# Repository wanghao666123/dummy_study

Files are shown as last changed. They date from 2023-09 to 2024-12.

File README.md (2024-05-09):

# Dummy
稚晖君dummy复制，目标是全国产谐波减速器，价格在3000元之内！
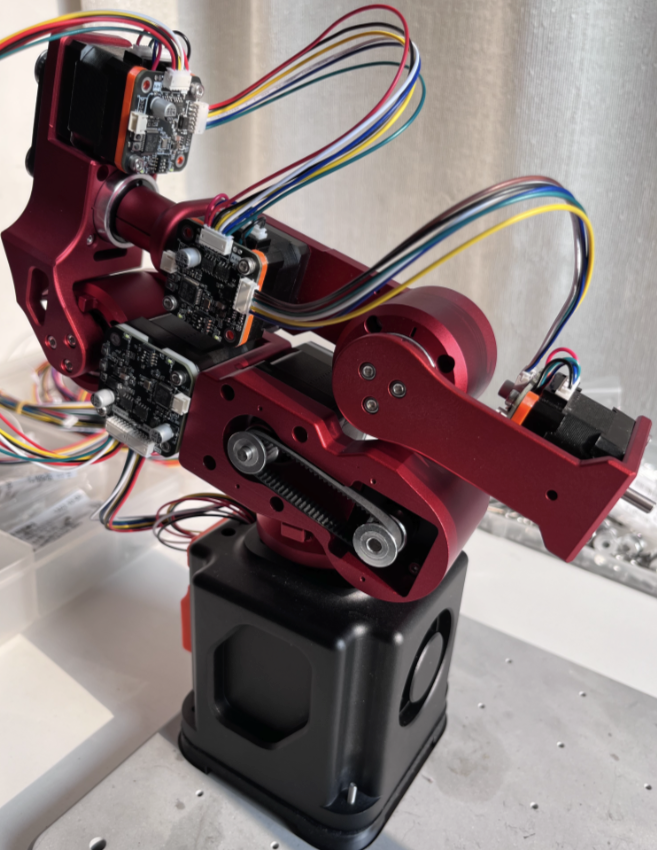
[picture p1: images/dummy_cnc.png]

1. 目录描述
- Firmware 包括ref控制板，42，35驱动板所用源代码
- Hardware 重新设计包括ref控制板，42，35驱动板schematic, pcb所有文件
- 3d-model 所有复制dummy 3d打印文件
- ESP32-iot esp32 supports files

1. 重新设计的ref控制板
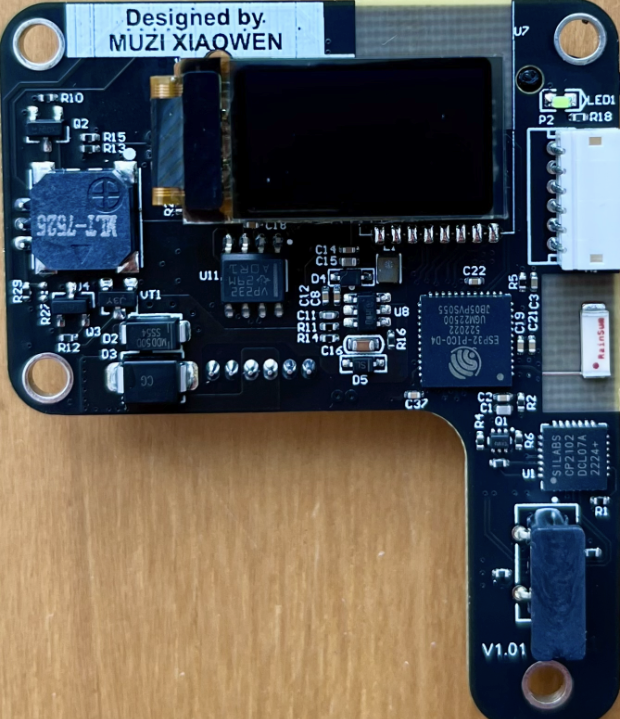
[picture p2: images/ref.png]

- 简化设计，更适合量产
1. 修改所有1.0mm的连接器为插针1.5mm，fix原版连接器容易脱落
1. 删除base板，将base板子集成到了主板上
1. 添加switching ldo，供电电流最大2A，fix原版mcu ldo电流过小，温度过高issue
1. 将led ring，buzzer 控制从ESP32 改到stm32 mcu
1. 更合理的布局
1. 降低量产成本

1. 重新设计的42/35驱动板

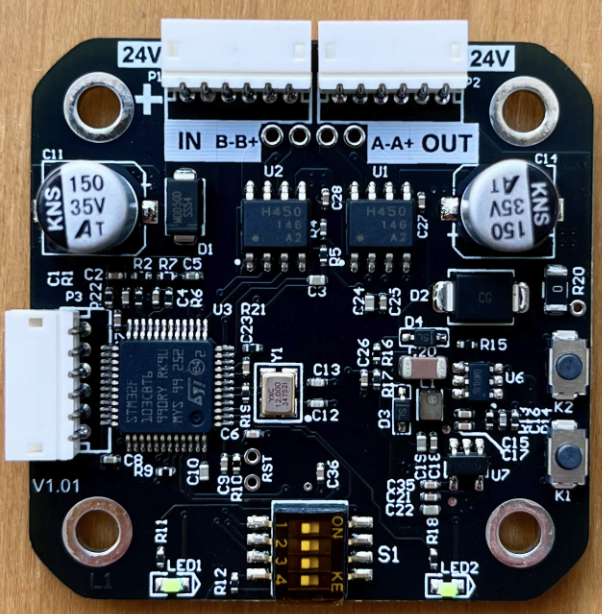
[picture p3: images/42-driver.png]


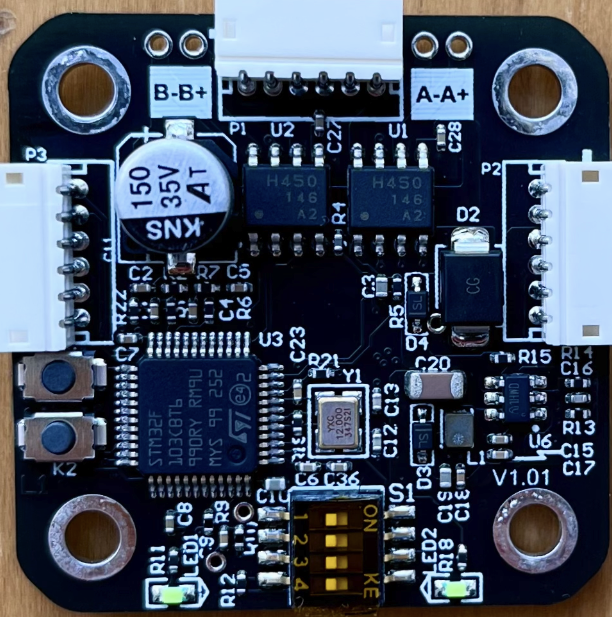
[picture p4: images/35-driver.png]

- 42/35驱动板正式版
1. 所有连接器改为1.5mm 3A 座子，更适合量产
1. 电源线复用两根1007/26号线，最大支持到3A
1. CAN BUS ID 通过板载拨码开关设置

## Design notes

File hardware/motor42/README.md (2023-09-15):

对比原始设计，优化了 PCB布局，模拟信号隔离，模拟电源隔离，隔离CAN总线，添加120欧姆终端电阻开关，加大了电源电容优化高转速启动性能，同时添加了多个低容值陶瓷电容优化了高频抗干扰性，提高了校验可靠性，提高了drive芯片的散热性能

--原理图基于并且拥有者稚晖君，原理图修改版和PCB设计木子晓文。--

Based on ZhiHuiJun schematic, the oringal design owned by ZhiHuiJun. Schematic modified and PCB designed by Muzi Xiaowen. 
The schematic and PCB design are free and open, and comes with ABSOLUTELY NO WARRANTY, to the extent permitted by applicable law.

References
https://github.com/peng-zhihui/Dummy-Robot

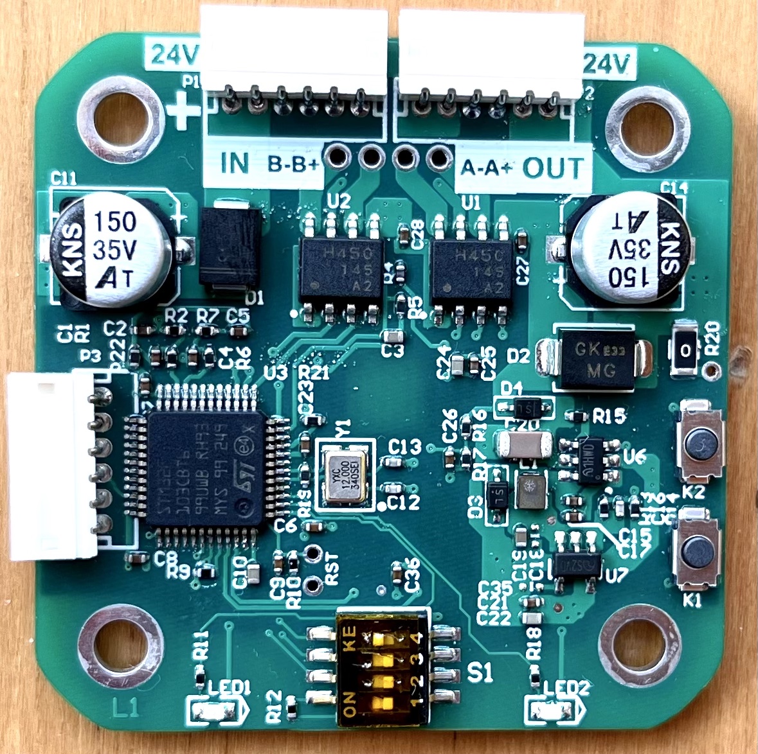
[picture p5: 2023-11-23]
images/m42.jpg

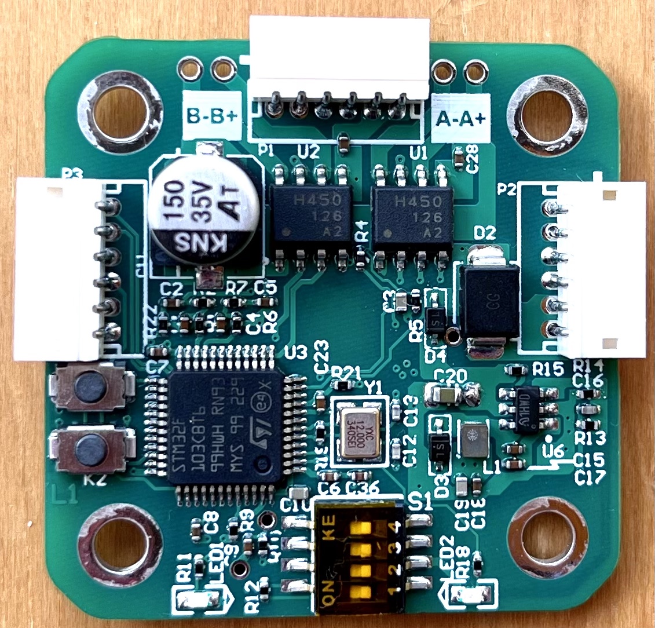
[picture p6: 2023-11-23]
images/m35.jpg

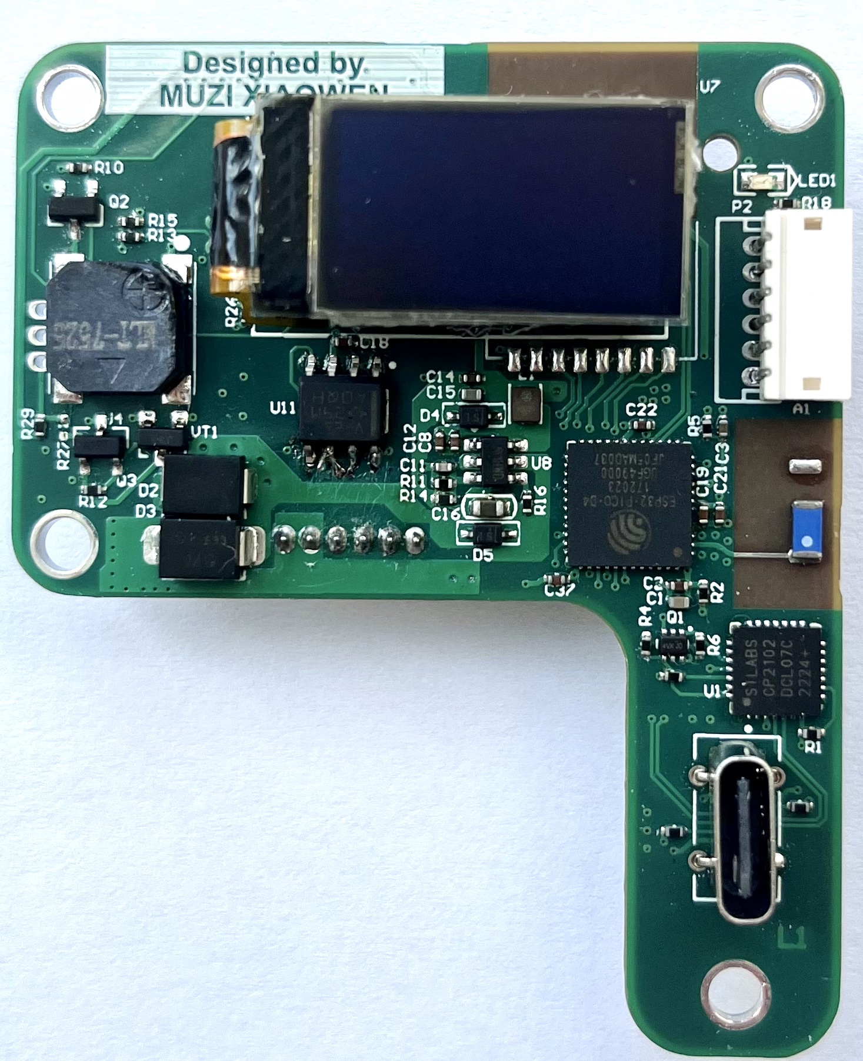
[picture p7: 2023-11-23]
images/controller_top.jpg

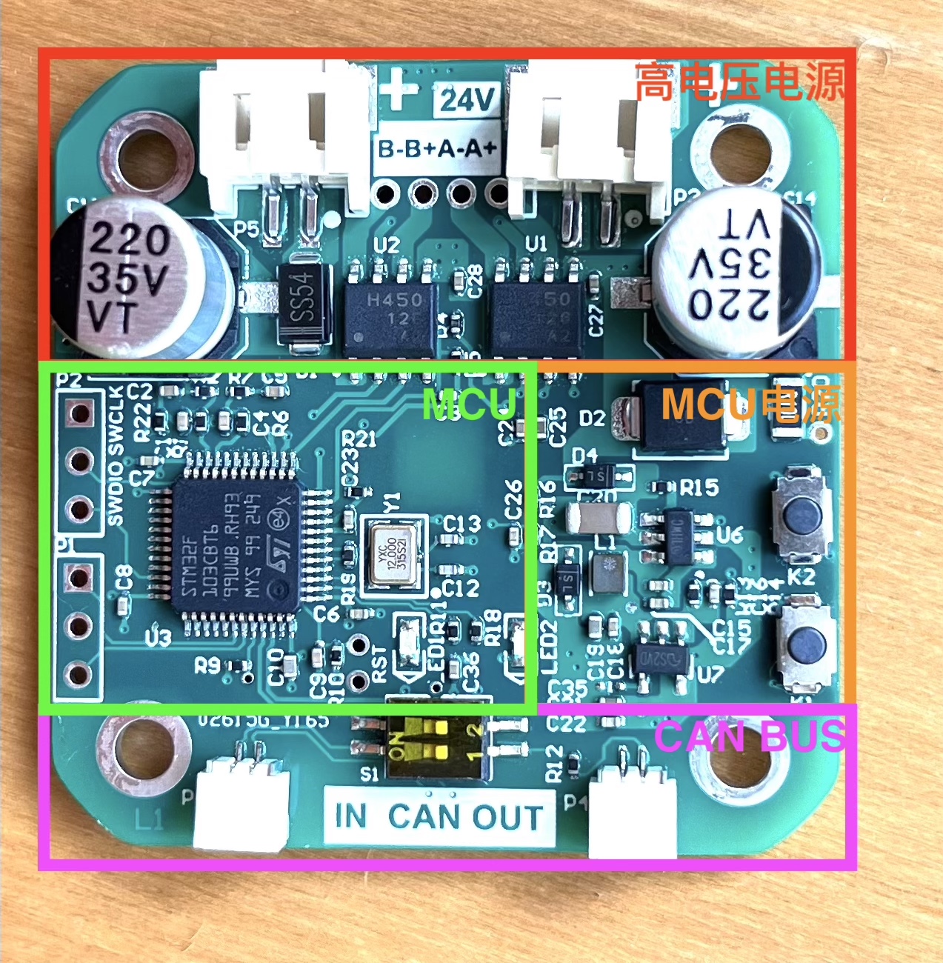
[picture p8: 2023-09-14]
images/top.jpg

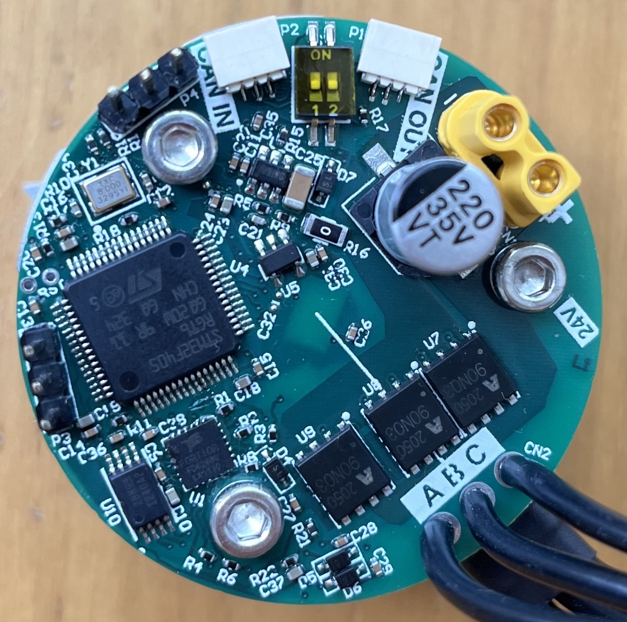
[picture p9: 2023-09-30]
images/bldc.jpg

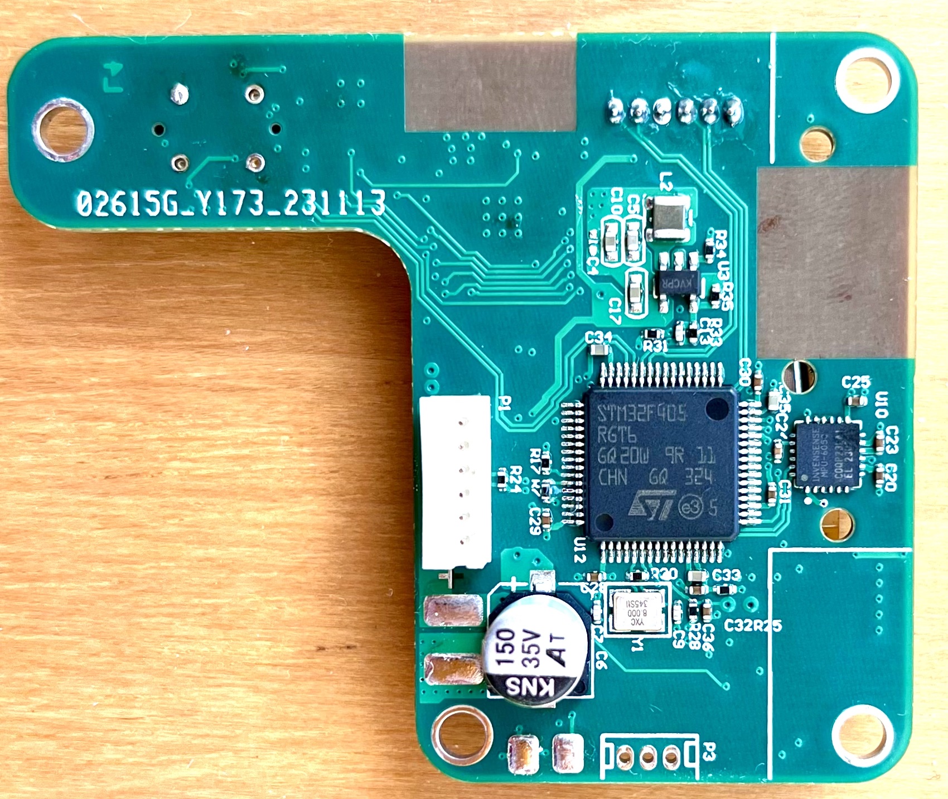
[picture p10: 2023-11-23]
images/controller_bot.jpg

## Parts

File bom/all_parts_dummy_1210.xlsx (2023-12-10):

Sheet: Motor-42
Comment | Description | Designator | Footprint | LibRef | Quantity
0.1uF | Capacitor | C1, C2, C4, C5, C6, C7, C8, C9, C15, C17, C18, C21, C25, C26 | CAP_0402 | 电容-0402 | 14
10uF | Capacitor | C3, C10, C19, C22, C24 | CAP_0402 | 电容-0402 | 5
100uF | Capacitor | C11, C12, C13, C14 | 1206-CAP | 电容-1206 | 4
100pF | Capacitor | C16 | CAP_0402 | 电容-0402 | 1
10uF/50V | Capacitor | C20 | CAP_0402 | 电容-0402 | 1
10nF | Capacitor | C23 | CAP_0402 | 电容-0402 | 1
SS54 | Diode | D1 | DO-214AC | Diode_SMA | 1
SMBJ28CA |  | D2 | SMBJ-CA_MFG | SMBJ28CA | 1
二极管-5819W | 40V | D3, D4 | SOD-323 | 二极管-5819W | 2
跳线 | Resistor | J1 | 0402-0R | 跳线 | 1
TACT 2P | Button | K1, K2 | ButtonTACT_3x4x2_180 | ButtonTACT_3x4x2_180 | 2
6.8uH |  | L1 | IND-201612 | 电感-201612 | 1
SH1.0-5P |  | P1 | SH1.0-5P | SH1.0-5P | 1
SH1.0-6P |  | P2, P3, P4 | SH1.0-6P | SH1.0-6P | 3
SH1.0-3P | Header | P5 | SH1.0-3P | SH1.0-3P | 1
1K | Resistor | R1, R2, R6, R7, R17 | RES_0402 | 电阻-0402 | 5
0.1R | Resistor | R3, R8 | 1206-RES | 电阻-1206 | 2
NCP15XH103F03RC | THERMISTOR 10K OHM NTC 0402 SMD | R4 | RES_0402 | NCP15XH103F03RC | 1
3.3K | Resistor | R5 | RES_0402 | 电阻-0402 | 1
10K | Resistor | R9, R10, R13, R16 | RES_0402 | 电阻-0402 | 4
120R | Resistor | R11, R12 | RES_0402 | 电阻-0402 | 2
1.8K | Resistor | R14 | RES_0402 | 电阻-0402 | 1
1M | Resistor | R15 | RES_0402 | 电阻-0402 | 1
测试点 |  | T1, T2 | TEST_PT | 测试点 | 2
TB67H450FNG | PWM Chopper Type DC Brushed Motor Driver | U1, U2 | SO-8-PAD | TB67H450FNG | 2
STM32F103CBT6 | ARM Cortex-M3 32-bit MCU, 128 KB Flash, 20 KB Internal RAM, 37 I/Os, 48-pin LQFP, -40 to 85 degC, Tray | U3 | LQFP-48 | STM32F103CBT6 | 1
TL431IDBZT | Adjustable precision shunt regulator 3-SOT-23 -40 to 85 | U4 | SOT23-3 | TL431IDBZT | 1 | taobao
SN65HVD232D |  | U5 | SO-8 | SN65HVD232D | 1
ME3116 | DC-DC | U6 | SOT23-6 | ME3116 | 1
LP2992 3V3 | LDO | U7 | SOT23-5 | LP2992 | 1
MT6816 | Magnetic Position Sensor | U8 | SO-8 | MT6816 | 1
12MHz | 村田贴片 | Y1 | 晶振-3P | 晶振-3Pin | 1 | taobao

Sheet: Motor-20
Comment | Description | Designator | Footprint | LibRef | Quantity
0.1uF | Capacitor | C1, C2, C3, C4, C5, C6, C7, C8, C11, C15, C16, C20, C21 | CAP_0402 | 电容-0402 | 13
100uF | Capacitor | C9, C10 | 1206-CAP | 电容-1206 | 2
10uF | Capacitor | C12, C17, C18, C19 | CAP_0402 | 电容-0402 | 4
10nF | Capacitor | C13 | CAP_0402 | 电容-0402 | 1
100pF | Capacitor | C14 | CAP_0402 | 电容-0402 | 1
SS54 | Diode | D1 | DO-214AC | Diode_SMA | 1
SMBJ28CA |  | D2 | SMBJ-CA_MFG | SMBJ28CA | 1
二极管-5819W | 40V | D3, D4 | SOD-323 | 二极管-5819W | 2
跳线 | Resistor | J1 | 0402-0R | 跳线 | 1
TACT 2P | Button | K1, K2 | ButtonTACT_3x4x2_180 | ButtonTACT_3x4x2_180 | 2
6.8uH |  | L1 | IND-201612 | 电感-201612 | 1
SH1.0-2P |  | P1, P2 | SH1.0-2P | SH1.0-2P | 2
SH1.0-3P | Header | P3 | SH1.0-3P | SH1.0-3P | 1
1K | Resistor | R1, R2, R4, R5, R14 | RES_0402 | 电阻-0402 | 5
0.1R | Resistor | R3, R6 | 1206-RES | 电阻-1206 | 2
10K | Resistor | R7, R8, R10, R13 | RES_0402 | 电阻-0402 | 4
120R | Resistor | R9 | RES_0402 | 电阻-0402 | 1
1.8K | Resistor | R11 | RES_0402 | 电阻-0402 | 1
1M | Resistor | R12 | RES_0402 | 电阻-0402 | 1
TB67H450FNG | PWM Chopper Type DC Brushed Motor Driver | U1, U2 | SO-8-PAD | TB67H450FNG | 2
STM32F103CBT6 | ARM Cortex-M3 32-bit MCU, 128 KB Flash, 20 KB Internal RAM, 37 I/Os, 48-pin LQFP, -40 to 85 degC, Tray | U3 | LQFP-48 | STM32F103CBT6 | 1
SN65HVD232D |  | U4 | SO-8 | SN65HVD232D | 1
LP2992 3V3 | LDO | U5 | SOT23-5 | LP2992 | 1
ME3116 | DC-DC | U6 | SOT23-6 | ME3116 | 1
MT6816 | Magnetic Position Sensor | U7 | SO-8 | MT6816 | 1
12MHz | 村田贴片 | Y1 | 晶振-3P | 晶振-3Pin | 1 | taobao

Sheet: REF-UNIT
Comment | Description | Designator | Footprint | LibRef | Quantity
OLED-12880 |  | 1 | OLED-12880 | OLED-12880 | 1
0.1uF | Capacitor | C1, C6, C7, C9, C12, C13, C14, C15, C16, C20 | CAP_0402 | 电容-0402 | 10
10uF | Capacitor | C2, C5, C10, C11, C17, C18, C19 | CAP_0402 | 电容-0402 | 7
10nF | Capacitor | C3, C4 | CAP_0402 | 电容-0402 | 2
2.2nF | Capacitor | C8 | CAP_0402 | 电容-0402 | 1
color? | LED | D1 | LED_0402_RED | LED_0402 | 1
B2B-Connector-28P-0.5mm |  | J1, J2 | B2B-0.5mm-28P-M | B2B-Connector-28P-0.5mm | 2
2K | Resistor | R1, R2, R3 | RES_0402 | 电阻-0402 | 3
4.7K | Resistor | R4, R5, R8 | RES_0402 | 电阻-0402 | 3
10K | Resistor | R6, R13 | RES_0402 | 电阻-0402 | 2
560K | Resistor | R7 | RES_0402 | 电阻-0402 | 1
120R/NC | Resistor | R9 | RES_0402 | 电阻-0402 | 1
0R | Resistor | R10, R11 | RES_0402 | 电阻-0402 | 2
22R | Resistor | R12, R14 | RES_0402 | 电阻-0402 | 2
LP2992 3V3 | LDO | U1 | SOT23-5 | LP2992 | 1
MPU6050 | 六轴传感器 | U2 | QFN-24 | MPU6050 | 1
SN65HVD232D |  | U3 | SO-8 | SN65HVD232D | 1
STM32F405RGT6 | ARM Cortex-M4 32-bit MCU+FPU, 210 DMIPS, 1024 kB Flash, 192 kB Internal RAM, 51 I/Os, 64-pin LQFP, -40 to 85 degC, Tray | U4 | LQFP-64_N | STM32F405RGT6 | 1
8MHz | 村田贴片 | Y1 | 晶振-3P | 晶振-3Pin | 1 | taobao

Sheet: REF-Base
Comment | Description | Designator | Footprint | LibRef | Quantity
RAINSUN |  | A1 | ANT-Rainsun-AN5120 | ANT-Rainsun-AP5120 | 1
10uF | Capacitor | C1, C5, C10, C15 | CAP_0402 | 电容-0402 | 4
0.1uF | Capacitor | C2, C4, C8, C9, C12, C14 | CAP_0402 | 电容-0402 | 6
1uF | Capacitor | C3 | CAP_0402 | 电容-0402 | 1
100uF | Capacitor | C6 | 1206-CAP | 电容-1206 | 1 | 22uF/35V
10nF | Capacitor | C7, C13 | CAP_0402 | 电容-0402 | 2
100pF | Capacitor | C11 | CAP_0402 | 电容-0402 | 1
10uF/50V | Capacitor | C16 | CAP_0402 | 电容-0402 | 1 | 2.2uF/35V
color? | LED | D1 | LED_0402_RED | LED_0402 | 1
SS54 | Diode | D2 | DO-214AC | Diode_SMA | 1
SMBJ28CA |  | D3 | SMBJ-CA_MFG | SMBJ28CA | 1
二极管-5819W | 40V | D4, D5 | SOD-323 | 二极管-5819W | 2
USB-TYPE-C-STAND |  | J1 | USB-TYPE-C-STAND | USB-TYPE-C-STAND | 1
6.8uH |  | L1 | IND-201612 | 电感-201612 | 1
SH1.0-5P |  | P1 | SH1.0-5P | SH1.0-5P | 1
SH1.0-2P |  | P2, P3, P4 | SH1.0-2P | SH1.0-2P | 3
SH1.0-3P | Header | P5, P6 | SH1.0-3P | SH1.0-3P | 2
BC847BVC-7 |  | Q1 | SOT563-6 | BC847BVC-7 | 1
AO3400A | N-MOS | Q2 | SOT23-3 | AO3400A | 1
AO3401A | P-MOS | Q3 | SOT23-3 | AO3401A | 1
10K | Resistor | R1, R5, R10, R11, R15 | RES_0402 | 电阻-0402 | 5
0R | Resistor | R2 | RES_0402 | 电阻-0402 | 1
200R | Resistor | R3 | RES_0402 | 电阻-0402 | 1
12K | Resistor | R4, R6 | RES_0402 | 电阻-0402 | 2
2K | Resistor | R7, R12 | RES_0402 | 电阻-0402 | 2
5.1K | Resistor | R8, R9 | RES_0402 | 电阻-0402 | 2
1K | Resistor | R13 | RES_0402 | 电阻-0402 | 1
1.8K | Resistor | R14 | RES_0402 | 电阻-0402 | 1
1M | Resistor | R16 | RES_0402 | 电阻-0402 | 1
REF-Unit | Robot Embedded Framework based on STM43F405RGT6. | S1 | REF-UNIT | REF-Unit | 1
CP2102 | USB转TTL | U1 | QFN-28 | CP2102 | 1
ESP32_SIP |  | U2 | QFN-48_7X7 | ESP32-PICO | 1
LP2992 3V3 | LDO | U3, U6 | SOT23-5 | LP2992 | 2
DET402 |  | U4 | DET402 | DET402 | 1
SN65HVD232D |  | U5 | SO-8 | SN65HVD232D | 1
NRF24L01 |  | U7 | NRF24L01-MODULE | NRF24L01模块 | 1
ME3116 | DC-DC | U8 | SOT23-6 | ME3116 | 1
S8050 | Surface mount NPN transistor, package SOT-23 | VT1 | SMT_TRIODE_NPN | SMT_TRIODE_NPN | 1

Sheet: screws
 |  | 数量
J1
M4*21mm |  | 2
M4*12MM | mini11 减速器到base外壳 | 2
M3*34MM | 42电机 | 4
M3*5MM | mini11 减速器适配件固定到42电机 | 2
M3*20MM | j1 固定到外壳 | 6
M3*18MM | j1 连杆固定到j2减速器 | 3
固定底座
M3*28MM | 固定到底座 | 4
J2/J3
M3*25 | 固定j2/j3减速器适配件 | 4
M3*30 | 固定j2/j3减速器到连杆 | 4
M3*15 | 固定j2 42 Motor到连杆 | 4
M3*42 | 固定3个 42 Motor 驱动板 | 12
M3*11MM | 固定j3 42 Motor到连杆 | 4
Joint4
M3*6MM | 固定j4 35 Motor到连杆 | 4
M3*13MM | 固定3个 35 Motor 驱动板 | 12
M3*13Mm | 固定j4减速器到连杆 | 3
Joint5
M3*8MM | 固定2个 35 Motor 到连杆 | 4
M3*19MM | 固定j5减速器到连杆 | 1

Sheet: 3d
 |  | 数量
Base.stl | joint1底座 | 1
joint23.stl | joint23联杆 | 1
joint4.stl | joint4联杆 | 1
joint5.stl | joint5联杆 | 1
joint6.stl | joint6联杆 | 1
mini11-bracket-metal.stl | mini11与42电机连接支架 | 1
mini8-bracket-metal.stl | mini8谐波连接支架 | 4
motor42-bracket-top-metal.stl | 42驱动板散热顶盖 | 3
motor35-bracket-top-metal.stl | 35驱动板散热顶盖 | 2

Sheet: parts
42电机驱动板 |  | 3 | b站 木子晓汶 工房
35电机驱动板 |  | 3 | b站 木子晓汶 工房
42 电机 | l=40 1a | 3 | https://item.taobao.com/item.htm?id=549501040122&ns=1&abbucket=13
35 电机 | l=28 1a | 3 | https://item.taobao.com/item.htm?spm=a1z09.2.0.0.17872e8dTWSTmP&id=15168111895&_u=83jnrl7aaaff
减速器 | mini11 | 1 | taobao
减速器 | mini8 | 5 | taobao
同步轮 | 20齿内孔5mm外径18 | 8 | https://item.taobao.com/item.htm?spm=a1z09.2.0.0.19b12e8dfRIPU3&id=625483500699&_u=a3jnrl7adc93
同步皮带 | 152mm | 1 | https://item.taobao.com/item.htm?spm=a1z09.2.0.0.19b12e8dfRIPU3&id=626759355655&_u=a3jnrl7aa476
同步皮带 | 120mm | 1 | https://item.taobao.com/item.htm?spm=a1z09.2.0.0.19b12e8dfRIPU3&id=626759355655&_u=a3jnrl7aa476
同步皮带 | 110mm | 1 | https://item.taobao.com/item.htm?spm=a1z09.2.0.0.19b12e8dfRIPU3&id=626759355655&_u=a3jnrl7aa476
同步皮带 | 184mm | 1 | https://item.taobao.com/item.htm?spm=a1z09.2.0.0.19b12e8dfRIPU3&id=626759355655&_u=a3jnrl7aa476
电源开关 | 开孔直径：16mm，12-24v | 1 | https://item.taobao.com/item.htm?spm=a1z09.2.0.0.6dcd2e8dgKFAl1&id=589544046782&_u=93jnrl7aceb2
DC电源插座 | DC5.5*2.5mm | 1 | https://item.taobao.com/item.htm?spm=a1z09.2.0.0.6dcd2e8dgKFAl1&id=679108658727&_u=93jnrl7a3b6f
电源 | 24v 6a | 1 | https://item.taobao.com/item.htm?spm=a1z09.2.0.0.6dcd2e8dgKFAl1&id=552809889509&_u=93jnrl7a25cd
6pin排线 | zh1.5mm 30CM(定做) | 1 | https://detail.tmall.com/item.htm?_u=93jnrl7a54c7&id=642559605753&spm=a1z09.2.0.0.6dcd2e8dgKFAl1
6pin排线 | zh1.5mm 20CM(定做) | 6 | https://detail.tmall.com/item.htm?_u=93jnrl7a54c7&id=642559605753&spm=a1z09.2.0.0.6dcd2e8dgKFAl1

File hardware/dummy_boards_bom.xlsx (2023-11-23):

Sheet: REF
Comment | Quantity | Designator | Footprint | Layer
0R | 4 | R2, R26, R27, R29 | RES_0402_1 | Top
0.1uF | 9 | C2, C8, C12, C14, C18, C19, C21, C22, C37 | CAP_0402 | Top
1K | 1 | R13 | RES_0402_1 | Top
1M | 1 | R16 | RES_0402_1 | Top
1uF | 1 | C3 | CAP_0402 | Top
1.8K | 1 | R14 | RES_0402_1 | Top
2K | 2 | R12, R18 | RES_0402_1 | Top
4.7K | 3 | R19, R20, R23 | RES_0402_1 | Top
4.7uF | 1 | C16 | C0603 | Top
5.1K | 2 | R8, R9 | RES_0402_1 | Top
6.8uH | 1 | L1 | IND-201612 | Top
10K | 6 | R1, R5, R10, R11, R15, R21 | RES_0402_1 | Top
10uF | 4 | C1, C15, C26, C27 | CAP_0402 | Top
12K | 2 | R4, R6 | RES_0402_1 | Top
100pF | 1 | C11 | CAP_0402 | Top
200R | 1 | R3 | RES_0402_1 | Top
560K | 1 | R22 | RES_0402_1 | Top
AO3400A | 1 | Q2 | SOT23-3 | Top
AO3401A | 1 | Q3 | SOT23-3 | Top
BC847BVC-7 | 1 | Q1 | SOT563-6 | Top
CP2102 | 1 | U1 | QFN-28 | Top
ESP32_SIP | 1 | U2 | QFN-48_7X7 | Top
Header 6H | 1 | P2 | CONN-TH_HC-ZH1.5-6A-s | Top
LED GREEN | 1 | LED1 | LED-0603 | Top
ME3116 | 1 | U8 | SOT23-6 | Top
MLT-7525 | 1 | U4 | BUZ-SMD_4P-L7.5-W7.5-P7.59-TL | Top
NRF24L01 | 1 | U7 | NRF24L01-MODULE | Top
OLED-12880 | 1 | 1 | OLED-12880 | Top
RAINSUN | 1 | A1 | ANT-Rainsun-AN5120 | Top
S8050 | 1 | VT1 | SMT_TRIODE_NPN | Top
SMBJ28CA | 1 | D3 | SMBJ-CA_MFG | Top
SN65HVD232D | 1 | U11 | SO-8 | Top
SS54 | 1 | D2 | DO-214AC | Top
USB-TYPE-C-STAND | 1 | J1 | USB-TYPE-C-STAND | Top
b5819W | 2 | D4, D5 | SOD-323 | Top
0R | 2 | R25, R31 | RES_0402_1 | Bottom
0.1uF | 10 | C4, C20, C23, C25, C28, C29, C30, C31, C32, C36 | CAP_0402 | Bottom
1M | 1 | R30 | RES_0402 | Bottom
2K | 2 | R7, R17 | RES_0402_1 | Bottom
2.2nF | 1 | C24 | CAP_0402 | Bottom
2.2uH | 1 | L2 | IND-252012A-2R2 | Bottom
10K | 2 | R28, R34 | RES_0402_1 | Bottom
10uF | 3 | C33, C34, C35 | CAP_0402 | Bottom
20pF | 2 | C7, C9 | CAP_0402 | Bottom
20pF | 1 | C13 | CAP_0402 | Bottom
22uF | 3 | C5, C10, C17 | C0603 | Bottom
22.1K | 1 | R35 | RES_0402_1 | Bottom
100K | 1 | R33 | RES_0402_1 | Bottom
120R/NC | 1 | R24 | RES_0402_1 | Bottom
220uF/25V | 1 | C6 | CAP-SMD_BD8.0-L8.3-W8.3-LS9.3-FD | Bottom
Header 3 | 1 | P3 | CONN-TH_HC-ZH1.5-3A-S | Bottom
Header 6H | 1 | P1 | CONN-TH_HC-ZH1.5-6A | Bottom
MPU6050 | 1 | U10 | QFN-24 | Bottom
STM32F405RGT6 | 1 | U12 | LQFP-64_N | Bottom
SY8089 2A | 1 | U3 | SOT23-5 | Bottom
XTAL-4 | 1 | Y1 | LC-SMD-3225_4P | Bottom

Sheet: Motor-42
Comment | Description | Designator | Footprint | Quantity | Layer
0.1R | Resistor | R3, R8 | 1206-RES | 2 | Bottom
10uF/50V | Capacitor, chip, ceramic | C29, C30, C31, C32, C33, C34 | 1206-CAP | 6 | Bottom
MT6816 | Magnetic Position Sensor | U8 | SO-8 | 1 | Bottom
SN65HVD232D |  | U5 | so-8 | 1 | Bottom
0 | Resistor | R21, R22 | RES_0402 | 2 | Top
0R | Resistor | R20 | 1206-RES | 1 | Top
0.1uF | Capacitor | C1, C2, C4, C5, C6, C7, C8, C9, C15, C17, C18, C21, C23, C25, C26, C27, C28, C35, C36 | CAP_0402 | 19 | Top
1K | Resistor | R1, R2, R6, R7, R11, R17, R18 | RES_0402 | 7 | Top
1M | Resistor | R15, R19 | RES_0402 | 2 | Top
1.8K | Resistor | R14 | RES_0402 | 1 | Top
3.3K | Resistor | R5 | RES_0402 | 1 | Top
6.8uH |  | L1 | IND-201612 | 1 | Top
10K | Resistor | R9, R10, R13, R16 | RES_0402 | 4 | Top
10uF | Capacitor | C3, C10, C19, C22, C24 | CAP_0402 | 5 | Top
10uF/50V | Capacitor | C20 | 1206-CAP | 1 | Top
20pF | Capacitor | C12, C13 | CAP_0402 | 2 | Top
100pF | Capacitor | C16 | CAP_0402 | 1 | Top
120R | Resistor | R12 | RES_0402 | 1 | Top
220uF/25V | Capacitor, chip, ceramic | C11, C14 | CAP-SMD_BD8.0-L8.3-W8.3-LS9.3-FD | 2 | Top
DSHP04TSGER | DIP Switches / SIP Switches 4 pos. low profile Btm Seal Tape J Bend | S1 | SW-SMD_DSHP04TS-S | 1 | Top
Header 6H | Header, 6-Pin, Right Angle | P1, P2, P3 | CONN-TH_HC-ZH1.5-6A-s | 3 | Top
LED GREEN | LED GRN SGL RA 25mA 4.1V SMD | LED1, LED2 | LED-0603 | 2 | Top
LP2992 3V3 | LDO | U7 | SOT23-5 | 1 | Top
ME3116 | DC-DC | U6 | SOT23-6 | 1 | Top
NCP15XH103F03RC | THERMISTOR 10K OHM NTC 0402 SMD | R4 | RES_0402 | 1 | Top
SMBJ28CA |  | D2 | SMBJ-CA_MFG | 1 | Top
SS54 | Diode | D1 | DO-214AC | 1 | Top
STM32F103CBT6 | ARM Cortex-M3 32-bit MCU, 128 KB Flash, 20 KB Internal RAM, 37 I/Os, 48-pin LQFP, -40 to 85 degC, Tray | U3 | LQFP-48 | 1 | Top
TACT 2P | Button | K1, K2 | ButtonTACT_3x4x2_180 | 2 | Top
TB67H450FNG | PWM Chopper Type DC Brushed Motor Driver | U1, U2 | SO-8-PAD | 2 | Top
XTAL-4 | Crystal | Y1 | LC-SMD-3225_4P | 1 | Top
二极管-5819W | 40V | D3, D4 | SOD-323 | 2 | Top

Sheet: Motor-35
Comment | Quantity | Description | Designator | Footprint | Layer
0R | 1 | Resistor | R20 | 1206-RES | Bottom
0.1R | 2 | Resistor | R3, R8 | 1206-RES | Bottom
0.1uF | 2 | Capacitor | C21, C25 | CAP_0402 | Bottom
10uF | 2 | Capacitor | C22, C24 | CAP_0402 | Bottom
10uF/50V | 4 | Capacitor, chip, ceramic | C29, C30, C31, C32 | 1206-CAP | Bottom
LP2992 3V3 | 1 | LDO | U7 | SOT23-5 | Bottom
MT6816 | 1 | Magnetic Position Sensor | U8 | SO-8 | Bottom
SN65HVD232D | 1 |  | U5 | so-8 | Bottom
SS54 | 1 | Diode | D1 | DO-214AC | Bottom
0 | 2 | Resistor | R21, R22 | RES_0402 | Top
0.1uF | 15 | Capacitor | C1, C2, C4, C5, C6, C7, C8, C9, C15, C17, C18, C23, C27, C28, C36 | CAP_0402 | Top
1K | 6 | Resistor | R1, R2, R6, R7, R11, R18 | RES_0402 | Top
1M | 2 | Resistor | R15, R19 | RES_0402 | Top
1.8K | 1 | Resistor | R14 | RES_0402 | Top
3.3K | 1 | Resistor | R5 | RES_0402 | Top
6.8uH | 1 |  | L1 | IND-201612 | Top
10K | 3 | Resistor | R9, R10, R13 | RES_0402 | Top
10uF | 3 | Capacitor | C3, C10, C19 | CAP_0402 | Top
10uF/50V | 1 | Capacitor | C20 | 1206-CAP | Top
20pF | 2 | Capacitor | C12, C13 | CAP_0402 | Top
100pF | 1 | Capacitor | C16 | CAP_0402 | Top
120R | 1 | Resistor | R12 | RES_0402 | Top
220uF/25V | 1 | Capacitor, chip, ceramic | C11 | CAP-SMD_BD8.0-L8.3-W8.3-LS9.3-FD | Top
DSHP04TSGER | 1 | DIP Switches / SIP Switches 4 pos. low profile Btm Seal Tape J Bend | S1 | SW-SMD_DSHP04TS-S | Top
Header 6H | 3 | Header, 6-Pin, Right Angle | P1, P2, P3 | CONN-TH_HC-ZH1.5-6A-s | Top
LED GREEN | 2 | LED GRN SGL RA 25mA 4.1V SMD | LED1, LED2 | LED-0603 | Top
ME3116 | 1 | DC-DC | U6 | SOT23-6 | Top
NCP15XH103F03RC | 1 | THERMISTOR 10K OHM NTC 0402 SMD | R4 | RES_0402 | Top
SMBJ28CA | 1 |  | D2 | SMBJ-CA_MFG | Top
STM32F103CBT6 | 1 | ARM Cortex-M3 32-bit MCU, 128 KB Flash, 20 KB Internal RAM, 37 I/Os, 48-pin LQFP, -40 to 85 degC, Tray | U3 | LQFP-48 | Top
TACT 2P | 2 | Button | K1, K2 | ButtonTACT_3x4x2_180 | Top
TB67H450FNG | 2 | PWM Chopper Type DC Brushed Motor Driver | U1, U2 | SO-8-PAD | Top
XTAL-4 | 1 | Crystal | Y1 | LC-SMD-3225_4P | Top
二极管-5819W | 2 | 40V | D3, D4 | SOD-323 | Top

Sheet: Screws
J1/BASE
M2*10 | 2 | fixs to controller enclosure
M3*20 | 4 | fixs to ground board
M4*20 | 2 | base to MINI11 reducer
M4*12 | 2 | MINI11 reducer bracket
M3*5 | 3 | for REF board fixs to base, flat header
M3*5 | 2 | MINI11 reducer bracket
M3*20 | 6 | MINI11 reducer adaptor to 42 Motor body
M3*20 | 3 | Joint1 link fixs to reducer
J2/J3
M3*25 | 16 | for all 4 mini8 reducer
M3*30 | 4 | for mini8 reducer fixs to arm
M3*15 | 4 | for 42 motor fixs to arm
M3*45 | 12 | for all 42 motor fixs to drive board
M3*12 | 4 | for j2/j3 up 42 motor fixs to arm
J4
M3*6 | 4 | for 35 motor fixs to arm
M3*12 | 12 | for all 35 motor fixs to drive board
J5
M3*8MM | 4 | for 35 motor fixs to arm
M3*19MM | 4 | for mini8 reducer fixs to arm
MINI8 Cover
M3*5 | 12
Bearing
5*10*4 | 5 | inner*outer*tall

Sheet: belts
J2 | 152MM
J3 | 120mm

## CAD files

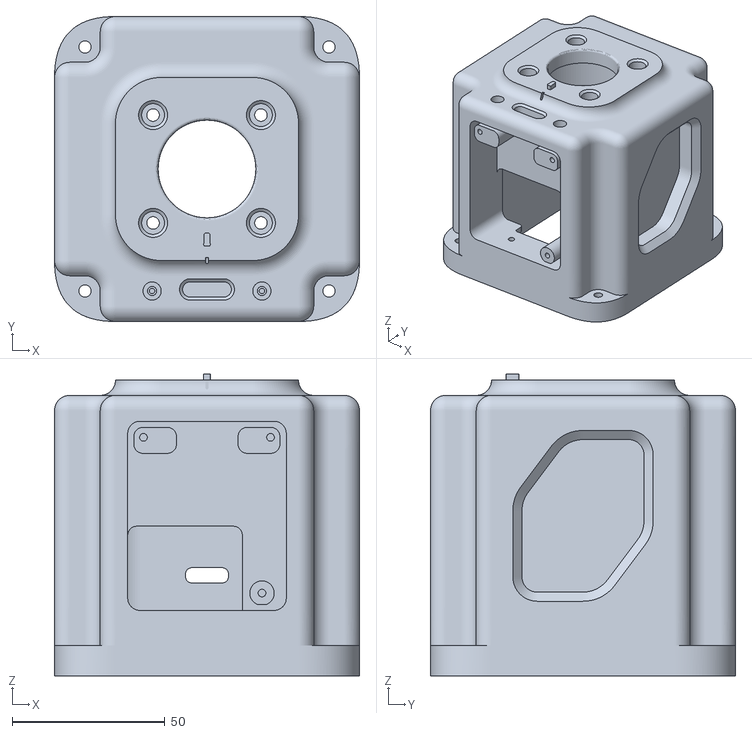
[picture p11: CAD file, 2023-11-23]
3d-model/base.stl
100.0 x 100.0 x 99.0

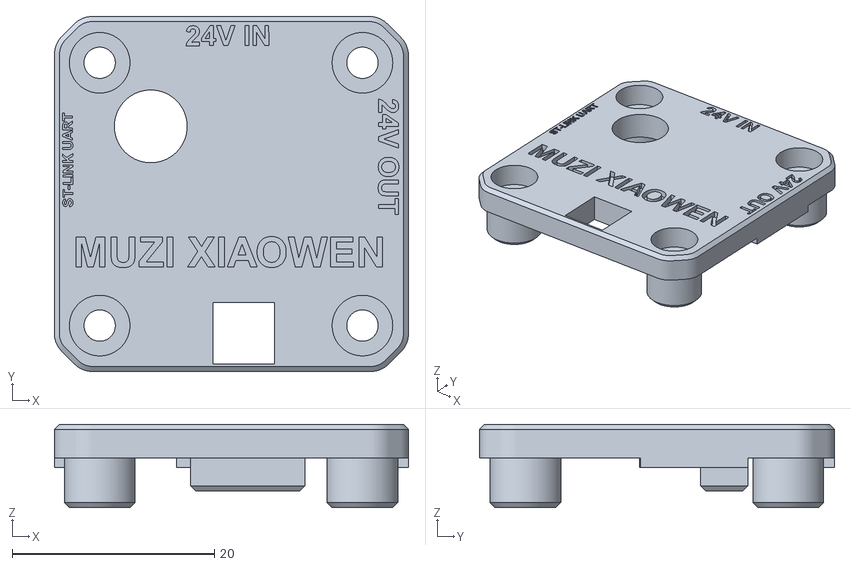
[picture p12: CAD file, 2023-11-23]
3d-model/m35/motor35-bracket-top-metal.stl
35.0 x 35.1 x 8.25

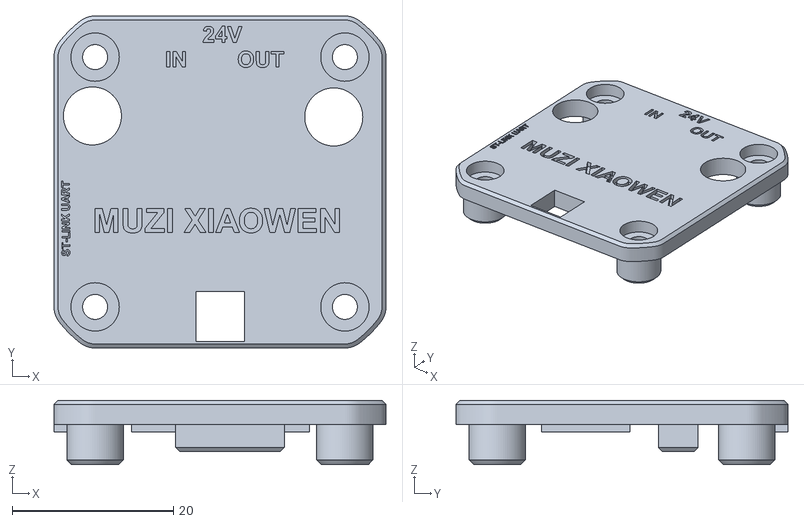
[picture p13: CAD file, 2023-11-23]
3d-model/m42/motor42-bracket-top-metal.stl
41.2 x 41.2 x 8.00

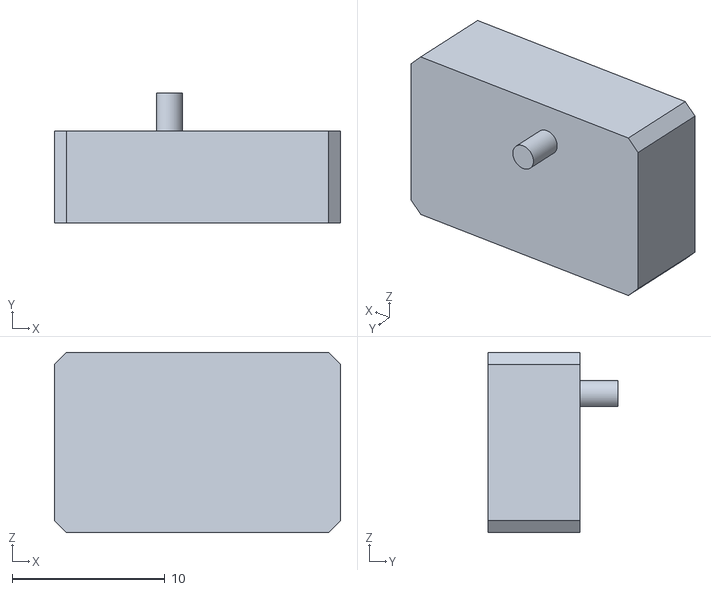
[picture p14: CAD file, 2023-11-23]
3d-model/ref-controller/contorller-oled-bracket.stl
18.7 x 8.50 x 11.8

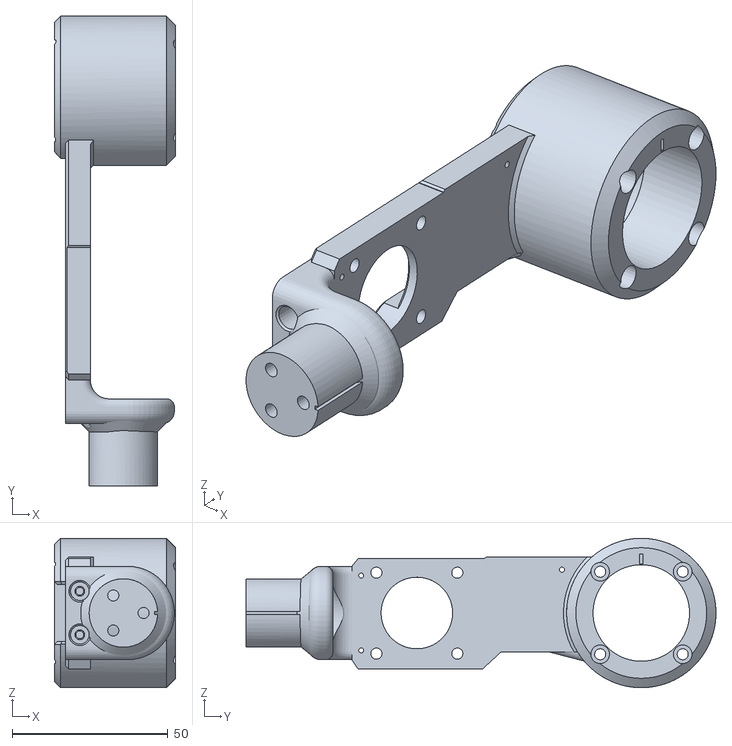
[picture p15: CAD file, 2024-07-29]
ros2/dummy_ws/src/dummy-ros2_description/meshes/link4_1_1.stl
39.0 x 151.0 x 48.0

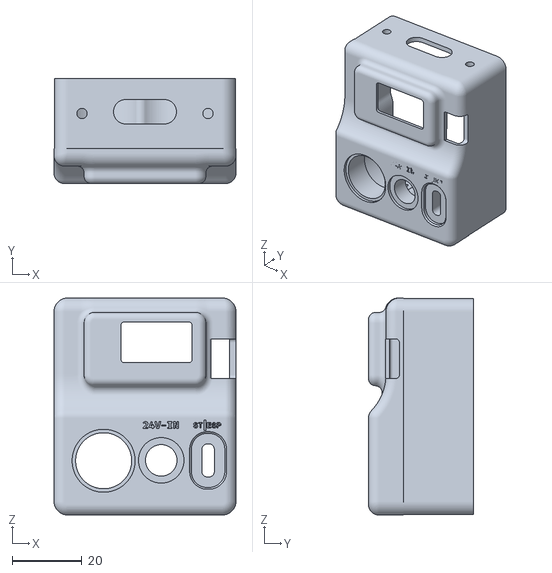
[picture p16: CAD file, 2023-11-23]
3d-model/controller_enclosure.stl
52.0 x 30.0 x 62.0

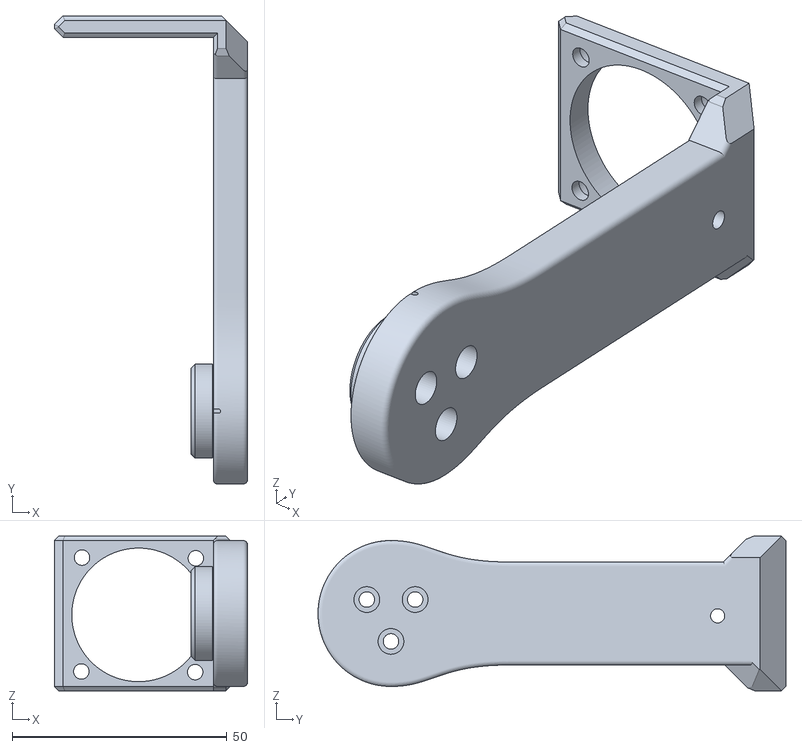
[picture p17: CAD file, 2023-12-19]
3d-model/latest/j6.stl
45.0 x 109.0 x 36.0

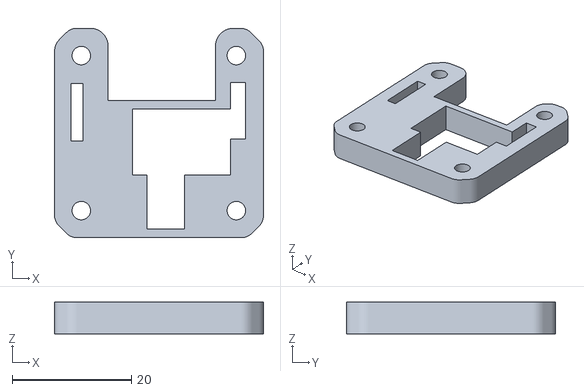
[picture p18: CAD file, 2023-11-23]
3d-model/m35/motor35-bracket-bot.stl
35.1 x 35.1 x 5.30

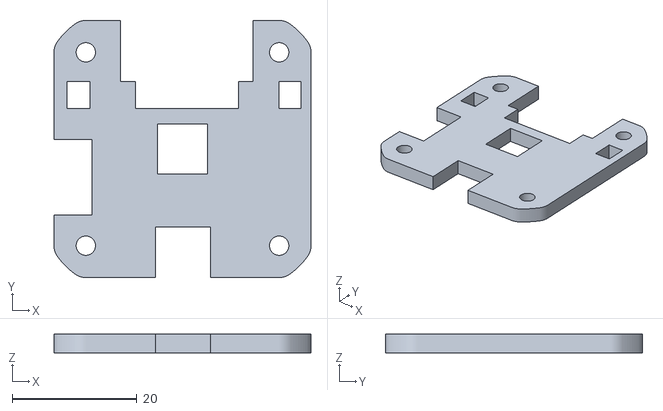
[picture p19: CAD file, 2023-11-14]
3d-model/m42/motor42-bracket-bot.stl
41.2 x 41.2 x 3.00

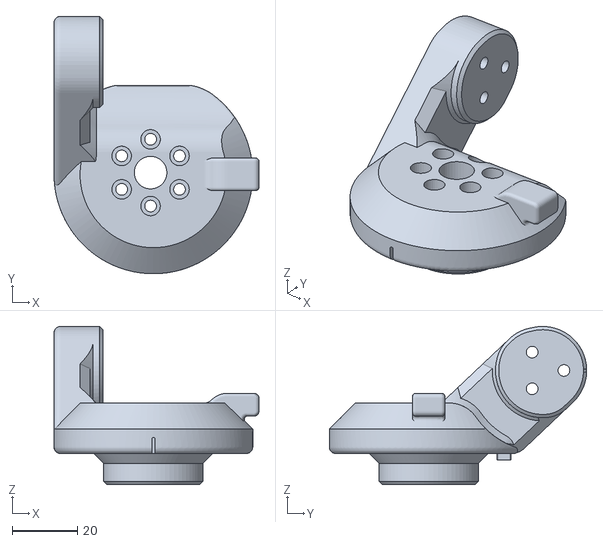
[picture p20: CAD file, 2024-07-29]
ros2/dummy_ws/src/dummy-ros2_description/meshes/link1_1_1.stl
62.9 x 79.0 x 48.5

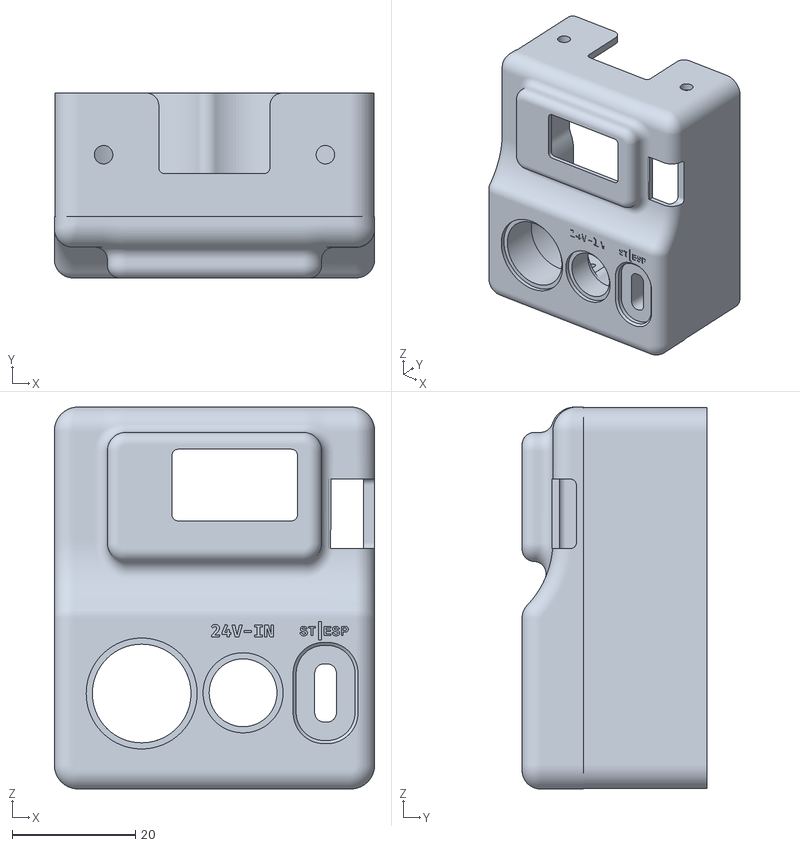
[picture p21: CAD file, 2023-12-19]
3d-model/latest/controller_enclosure.stl
52.0 x 30.0 x 62.0

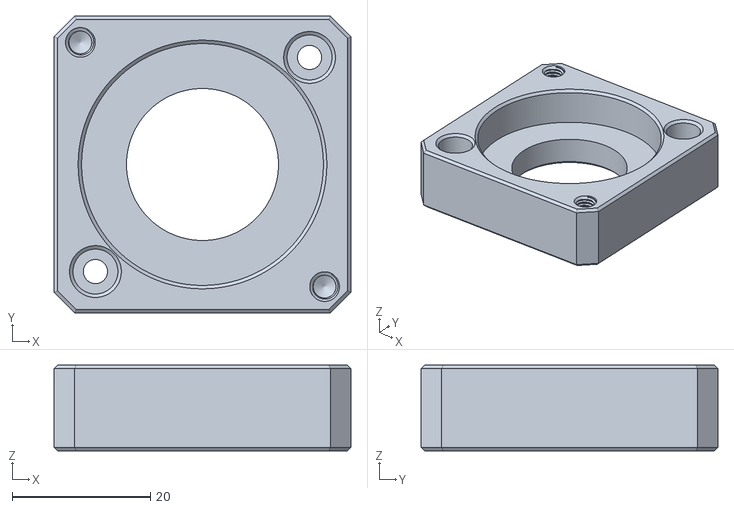
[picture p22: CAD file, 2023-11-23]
3d-model/mini11-bracket-metal.stl
43.0 x 43.0 x 12.4

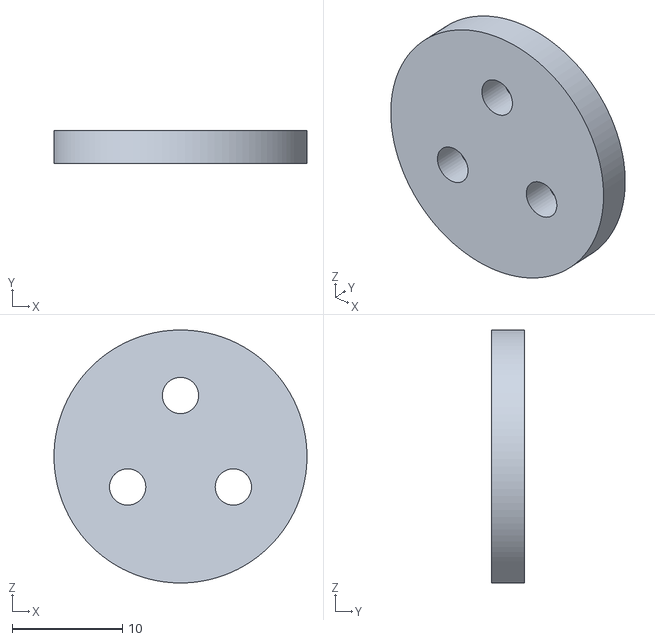
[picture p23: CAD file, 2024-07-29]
ros2/dummy_ws/src/dummy-ros2_description/meshes/link6_1_1.stl
23.0 x 3.00 x 23.0

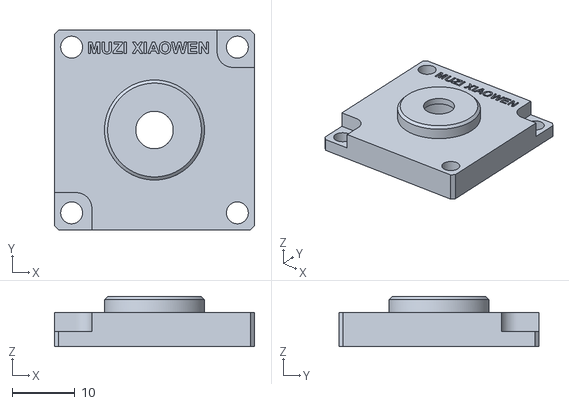
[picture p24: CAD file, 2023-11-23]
3d-model/mini8-bracket-metal.stl
32.0 x 32.0 x 8.00

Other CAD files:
3d-model/latest/base.stl
3d-model/latest/j1.stl
ros2/dummy_ws/src/dummy-ros2_description/meshes/link2_1_1.stl
3d-model/joint5.stl
3d-model/joint1.stl
3d-model/joint23.stl
3d-model/joint4.stl
3d-model/joint6.stl
3d-model/latest/j2j3.stl
3d-model/latest/j4.stl
3d-model/latest/j5.stl
ros2/dummy_ws/src/dummy-ros2_description/meshes/base_link.stl
ros2/dummy_ws/src/dummy-ros2_description/meshes/link3_1_1.stl
ros2/dummy_ws/src/dummy-ros2_description/meshes/link5_1_1.stl

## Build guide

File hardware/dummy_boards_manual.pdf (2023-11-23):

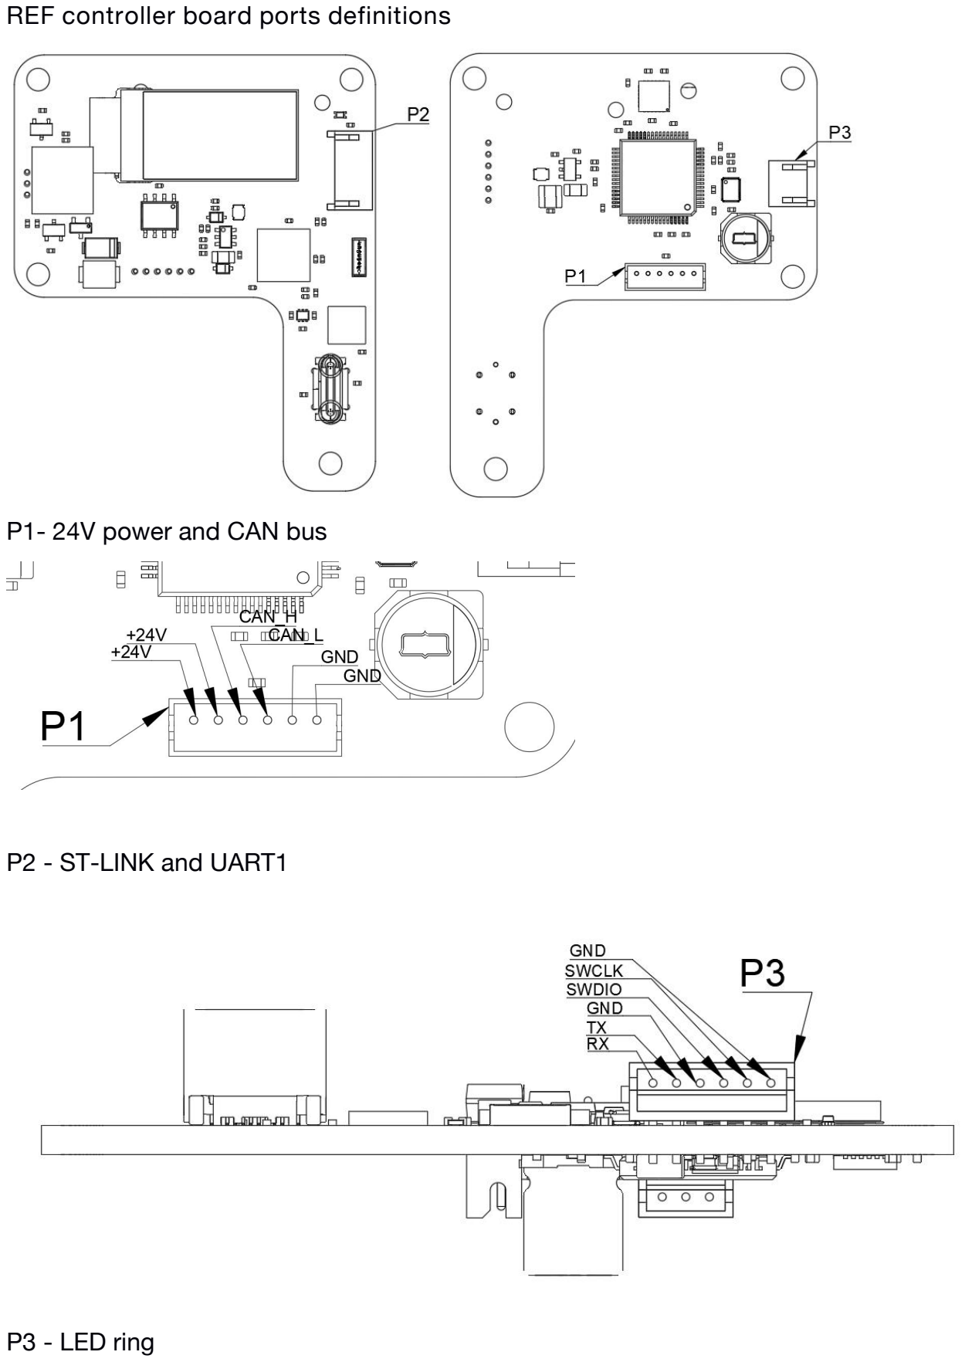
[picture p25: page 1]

REF controller board ports definitions

P1- 24V power and CAN bus

P2 - ST-LINK and UART1

P3 - LED ring

Motor 42 driver board ports definitions

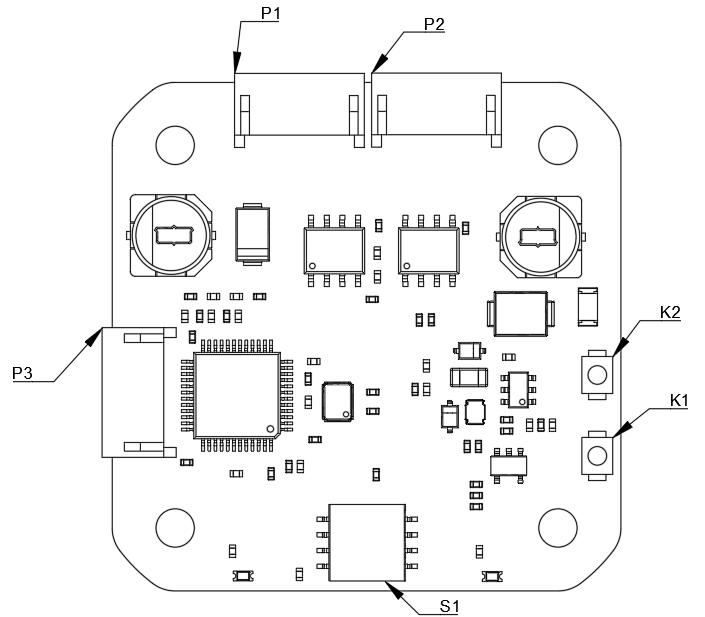
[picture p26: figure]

P1/P2 - 24V power and CAN bus(The below diagram shows P1 and P2 have same pins definition)

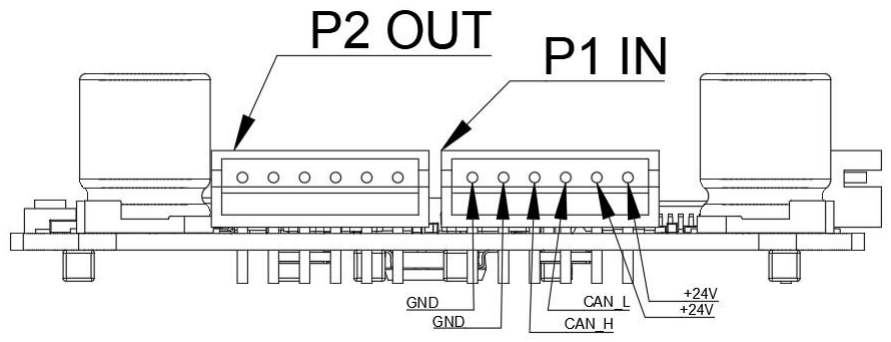
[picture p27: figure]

P3 - ST-LINK and UART1

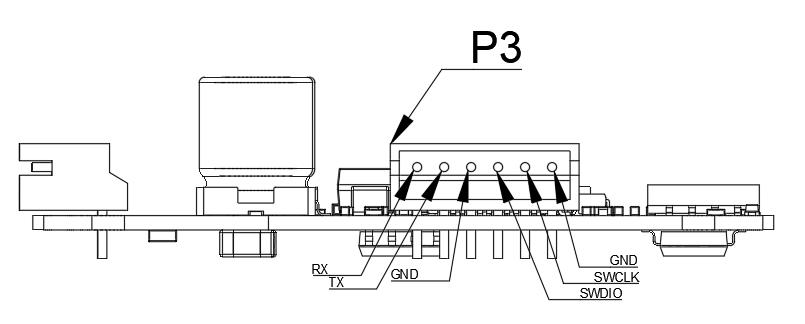
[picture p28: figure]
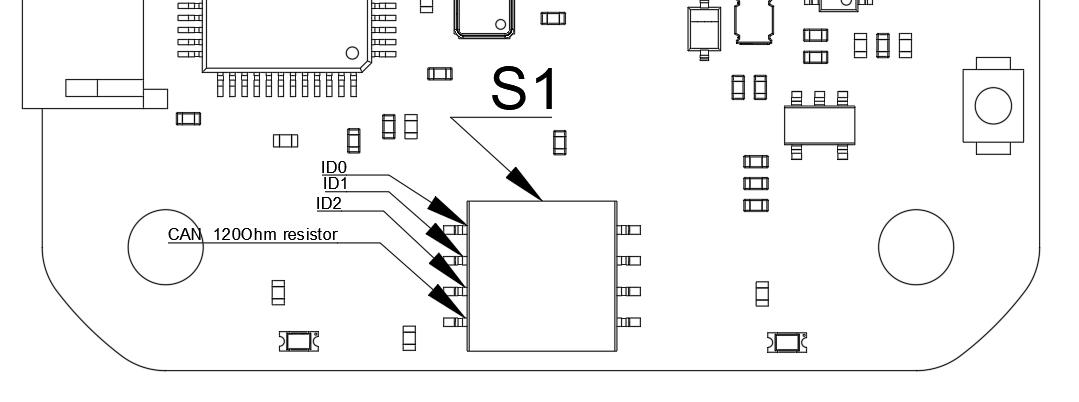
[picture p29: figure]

S1 - Driver board CAN ID definition and terminal resistor

CAN ID definition details

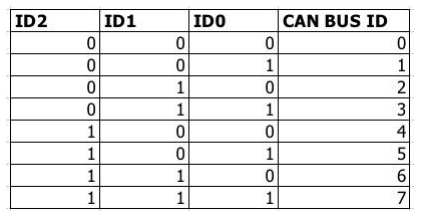
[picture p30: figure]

Motor 35 driver board ports definitions

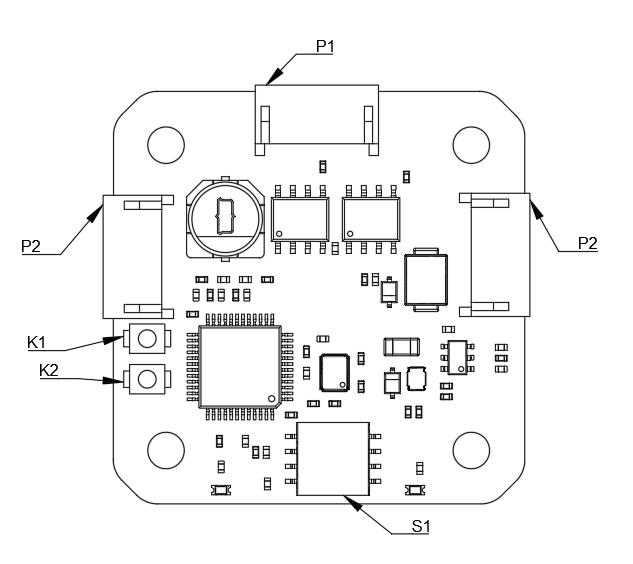
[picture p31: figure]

P1/P2 - 24V power and CAN bus(P1 and P2 share same pins definition with Motor 42 P1 and P2)

P3 - ST-LINK and UART1 (P3 shares same pins definition with Motor 42 P2)

S1 - Driver board CAN ID definition and terminal resistor(S1 shares same pins definition with Motor 42 S1)

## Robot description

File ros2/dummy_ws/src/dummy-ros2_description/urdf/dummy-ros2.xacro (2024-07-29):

<?xml version="1.0" ?>
<robot name="dummy-ros2" xmlns:xacro="http://www.ros.org/wiki/xacro">

<xacro:include filename="$(find dummy-ros2_description)/urdf/materials.xacro" />
<xacro:include filename="$(find dummy-ros2_description)/urdf/dummy-ros2.trans" />
<xacro:include filename="$(find dummy-ros2_description)/urdf/dummy-ros2.gazebo" />
<link name="world" />
<joint name="world_joint" type="fixed">
  <parent link="world" />
  <child link = "base_link" />
  <origin xyz="0.0 0.0 0.0" rpy="3.1415926536 3.1415926536 0.0" />
</joint>

<link name="base_link">
  <inertial>
    <origin xyz="-0.019286443307707055 0.0005817485706867557 0.05546290448958129" rpy="0 0 0"/>
    <mass value="3.4054232030550327"/>
    <inertia ixx="0.006318" iyy="0.00644" izz="0.006723" ixy="-1.1e-05" iyz="-0.000164" ixz="-2e-06"/>
  </inertial>
  <visual>
    <origin xyz="0 0 0" rpy="0 0 0"/>
    <geometry>
      <mesh filename="file://$(find dummy-ros2_description)/meshes/base_link.stl" scale="0.001 0.001 0.001"/>
    </geometry>
    <material name="silver"/>
  </visual>
  <collision>
    <origin xyz="0 0 0" rpy="0 0 0"/>
    <geometry>
      <mesh filename="file://$(find dummy-ros2_description)/meshes/base_link.stl" scale="0.001 0.001 0.001"/>
    </geometry>
  </collision>
</link>

<link name="link1_1_1">
  <inertial>
    <origin xyz="-0.005744742318232344 0.005464327027038366 0.012045619429015192" rpy="0 0 0"/>
    <mass value="0.4000119946706078"/>
    <inertia ixx="0.000172" iyy="0.000152" izz="0.00025" ixy="5.8e-05" iyz="-3.9e-05" ixz="2.7e-05"/>
  </inertial>
  <visual>
    <origin xyz="0.019225 0.000523 -0.100684" rpy="0 0 0"/>
    <geometry>
      <mesh filename="file://$(find dummy-ros2_description)/meshes/link1_1_1.stl" scale="0.001 0.001 0.001"/>
    </geometry>
    <material name="silver"/>
  </visual>
  <collision>
    <origin xyz="0.019225 0.000523 -0.100684" rpy="0 0 0"/>
    <geometry>
      <mesh filename="file://$(find dummy-ros2_description)/meshes/link1_1_1.stl" scale="0.001 0.001 0.001"/>
    </geometry>
  </collision>
</link>

<link name="link2_1_1">
  <inertial>
    <origin xyz="0.022476329402049397 0.0015836740439541114 0.0701478637986927" rpy="0 0 0"/>
    <mass value="0.9644194016592866"/>
    <inertia ixx="0.003808" iyy="0.003848" izz="0.000499" ixy="-1e-05" iyz="1.3e-05" ixz="0.000274"/>
  </inertial>
  <visual>
    <origin xyz="0.034725 -0.034477 -0.129184" rpy="0 0 0"/>
    <geometry>
      <mesh filename="file://$(find dummy-ros2_description)/meshes/link2_1_1.stl" scale="0.001 0.001 0.001"/>
    </geometry>
    <material name="silver"/>
  </visual>
  <collision>
    <origin xyz="0.034725 -0.034477 -0.129184" rpy="0 0 0"/>
    <geometry>
      <mesh filename="file://$(find dummy-ros2_description)/meshes/link2_1_1.stl" scale="0.001 0.001 0.001"/>
    </geometry>
  </collision>
</link>

<link name="link3_1_1">
  <inertial>
    <origin xyz="-0.010730263185093621 -0.022369081214190782 0.036467614070683996" rpy="0 0 0"/>
    <mass value="0.3817226974329336"/>
    <inertia ixx="0.000328" iyy="0.00037" izz="0.000146" ixy="-2.4e-05" iyz="6.8e-05" ixz="6.5e-05"/>
  </inertial>
  <visual>
    <origin xyz="-0.001925 -0.034477 -0.275184" rpy="0 0 0"/>
    <geometry>
      <mesh filename="file://$(find dummy-ros2_description)/meshes/link3_1_1.stl" scale="0.001 0.001 0.001"/>
    </geometry>
    <material name="silver"/>
  </visual>
  <collision>
    <origin xyz="-0.001925 -0.034477 -0.275184" rpy="0 0 0"/>
    <geometry>
      <mesh filename="file://$(find dummy-ros2_description)/meshes/link3_1_1.stl" scale="0.001 0.001 0.001"/>
    </geometry>
  </collision>
</link>

<link name="link4_1_1">
  <inertial>
    <origin xyz="-0.004221306676286125 0.09021372117053507 0.00026828289249919424" rpy="0 0 0"/>
    <mass value="0.44370009904209484"/>
    <inertia ixx="0.001103" iyy="0.00012" izz="0.001078" ixy="-3.2e-05" iyz="-1e-06" ixz="1e-06"/>
  </inertial>
  <visual>
    <origin xyz="0.016625 -0.024477 -0.327184" rpy="0 0 0"/>
    <geometry>
      <mesh filename="file://$(find dummy-ros2_description)/meshes/link4_1_1.stl" scale="0.001 0.001 0.001"/>
    </geometry>
    <material name="silver"/>
  </visual>
  <collision>
    <origin xyz="0.016625 -0.024477 -0.327184" rpy="0 0 0"/>
    <geometry>
      <mesh filename="file://$(find dummy-ros2_description)/meshes/link4_1_1.stl" scale="0.001 0.001 0.001"/>
    </geometry>
  </collision>
</link>

<link name="link5_1_1">
  <inertial>
    <origin xyz="-0.0007044959912857188 0.04181588666040692 1.9856549020258463e-05" rpy="0 0 0"/>
    <mass value="0.1329416987985629"/>
    <inertia ixx="0.000148" iyy="3.5e-05" izz="0.00016" ixy="3e-05" iyz="-0.0" ixz="0.0"/>
  </inertial>
  <visual>
    <origin xyz="-0.000175 -0.151477 -0.327184" rpy="0 0 0"/>
    <geometry>
      <mesh filename="file://$(find dummy-ros2_description)/meshes/link5_1_1.stl" scale="0.001 0.001 0.001"/>
    </geometry>
    <material name="silver"/>
  </visual>
  <collision>
    <origin xyz="-0.000175 -0.151477 -0.327184" rpy="0 0 0"/>
    <geometry>
      <mesh filename="file://$(find dummy-ros2_description)/meshes/link5_1_1.stl" scale="0.001 0.001 0.001"/>
    </geometry>
  </collision>
</link>

<link name="link6_1_1">
  <inertial>
    <origin xyz="8.866549679534264e-08 0.001500477150790519 2.701463612808652e-07" rpy="0 0 0"/>
    <mass value="0.00918018258883941"/>
    <inertia ixx="0.0" iyy="1e-06" izz="0.0" ixy="0.0" iyz="0.0" ixz="-0.0"/>
  </inertial>
  <visual>
    <origin xyz="0.018331 -0.228477 -0.327078" rpy="0 0 0"/>
    <geometry>
      <mesh filename="file://$(find dummy-ros2_description)/meshes/link6_1_1.stl" scale="0.001 0.001 0.001"/>
    </geometry>
    <material name="silver"/>
  </visual>
  <collision>
    <origin xyz="0.018331 -0.228477 -0.327078" rpy="0 0 0"/>
    <geometry>
      <mesh filename="file://$(find dummy-ros2_description)/meshes/link6_1_1.stl" scale="0.001 0.001 0.001"/>
    </geometry>
  </collision>
</link>

<joint name="Joint1" type="revolute">
  <origin xyz="-0.019225 -0.000523 0.100684" rpy="0 0 0"/>
  <parent link="base_link"/>
  <child link="link1_1_1"/>
  <axis xyz="0.0 -0.0 -1.0"/>
  <limit lower="-3.14" upper="3.14" effort="150" velocity="3.15" />
</joint>

<joint name="Joint2" type="revolute">
  <origin xyz="-0.0155 0.035 0.0285" rpy="0 0 0"/>
  <parent link="link1_1_1"/>
  <child link="link2_1_1"/>
  <axis xyz="-1.0 -0.0 0.0"/>
  <limit lower="-3.14" upper="3.14" effort="150" velocity="3.15" />
</joint>

<joint name="Joint3" type="revolute">
  <origin xyz="0.03665 0.0 0.146" rpy="0 0 0"/>
  <parent link="link2_1_1"/>
  <child link="link3_1_1"/>
  <axis xyz="-1.0 0.0 -0.0"/>
  <limit lower="-3.14" upper="3.14" effort="150" velocity="3.15" />
</joint>

<joint name="Joint4" type="revolute">
  <origin xyz="-0.01855 -0.01 0.052" rpy="0 0 0"/>
  <parent link="link3_1_1"/>
  <child link="link4_1_1"/>
  <axis xyz="0.0 -1.0 0.0"/>
  <limit lower="-3.14" upper="3.14" effort="150" velocity="3.15" />
</joint>

<joint name="Joint5" type="revolute">
  <origin xyz="0.0168 0.127 0.0" rpy="0 0 0"/>
  <parent link="link4_1_1"/>
  <child link="link5_1_1"/>
  <axis xyz="-1.0 0.0 -0.0"/>
  <limit lower="-3.14" upper="3.14" effort="150" velocity="3.15" />
</joint>

<joint name="Joint6" type="revolute">
  <origin xyz="-0.018506 0.077 -0.000106" rpy="0 0 0"/>
  <parent link="link5_1_1"/>
  <child link="link6_1_1"/>
  <axis xyz="-0.0 -1.0 0.0"/>
  <limit lower="-3.14" upper="3.14" effort="150" velocity="3.15" />
</joint>

</robot>

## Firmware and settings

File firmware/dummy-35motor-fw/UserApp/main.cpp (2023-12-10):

#include "common_inc.h"
#include "configurations.h"
#include "Platform/Utils/st_hardware.h"
#include <tim.h>


/* Component Definitions -----------------------------------------------------*/
BoardConfig_t boardConfig;
Motor motor;
TB67H450 tb67H450;
MT6816 mt6816;
EncoderCalibrator encoderCalibrator(&motor);
Button button1(1, 1000), button2(2, 3000);
void OnButton1Event(Button::Event _event);
void OnButton2Event(Button::Event _event);
Led statusLed;
/* Main Entry ----------------------------------------------------------------*/
void Main()
{
    uint64_t serialNum = GetSerialNumber();
    uint16_t defaultNodeID = 0;
    //ID0 is PA8 -->  Switch 4
    //ID1 is PA9 -->  Switch 3
    //ID2 is PA10 --> Switch 2
    uint16_t nodeID = !HAL_GPIO_ReadPin(GPIOA, ID0_Pin);
    nodeID |= !HAL_GPIO_ReadPin(GPIOA, ID1_Pin) << 1;
    nodeID |= !HAL_GPIO_ReadPin(GPIOA, ID2_Pin) << 2;
    defaultNodeID = nodeID;

    /*---------- Apply EEPROM Settings ----------*/
    // Setting priority is EEPROM > Motor.h
    EEPROM eeprom;
    eeprom.get(0, boardConfig);
    if (boardConfig.configStatus != CONFIG_OK) // use default settings
    {
        boardConfig = BoardConfig_t{
            .configStatus = CONFIG_OK,
//            .canNodeId = defaultNodeID,
            .encoderHomeOffset = 0,
            .defaultMode = Motor::MODE_COMMAND_POSITION,
            .currentLimit = 1 * 1000,    // A
            .velocityLimit = 30 * motor.MOTOR_ONE_CIRCLE_SUBDIVIDE_STEPS, // r/s
            .velocityAcc = 100 * motor.MOTOR_ONE_CIRCLE_SUBDIVIDE_STEPS,   // r/s^2
            .calibrationCurrent=2000,
            .dce_kp = 195,
            .dce_kv = 80,
            .dce_ki = 300,
            .dce_kd = 250,
            .motor_temperature = 0.0,
            .enableMotorOnBoot=false,
            .enableStallProtect=false,
            .enableTempWatch=false,
        };
        eeprom.put(0, boardConfig);
    }
    boardConfig.enableTempWatch=false;
    //depends on 3 bits switch now
    boardConfig.canNodeId = defaultNodeID;
    motor.config.motionParams.encoderHomeOffset = boardConfig.encoderHomeOffset;
    motor.config.motionParams.ratedCurrent = boardConfig.currentLimit;
    motor.config.motionParams.ratedVelocity = boardConfig.velocityLimit;
    motor.config.motionParams.ratedVelocityAcc = boardConfig.velocityAcc;
    motor.motionPlanner.velocityTracker.SetVelocityAcc(boardConfig.velocityAcc);
    motor.motionPlanner.positionTracker.SetVelocityAcc(boardConfig.velocityAcc);
    motor.config.motionParams.caliCurrent = boardConfig.calibrationCurrent;
    motor.config.ctrlParams.dce.kp = boardConfig.dce_kp;
    motor.config.ctrlParams.dce.kv = boardConfig.dce_kv;
    motor.config.ctrlParams.dce.ki = boardConfig.dce_ki;
    motor.config.ctrlParams.dce.kd = boardConfig.dce_kd;
    motor.config.ctrlParams.stallProtectSwitch = boardConfig.enableStallProtect;


//    printf("encoderHomeOffset[%d] ratedCurrent[%d] ratedVelocity[%d] ratedVelocityAcc[%d]\r\n" , boardConfig.encoderHomeOffset, boardConfig.currentLimit, boardConfig.velocityLimit, boardConfig.velocityAcc);
//    printf("velocityTracker[%d] positionTracker[%d] caliCurrent[%d] \r\n" , boardConfig.velocityAcc, boardConfig.velocityAcc);
//    printf("kp[%d] kv[%d] ki[%d] kd[%d]\r\n" , boardConfig.dce_kp, boardConfig.dce_kv, boardConfig.dce_ki, boardConfig.dce_kd);


    /*---------------- Init Motor ----------------*/
    motor.AttachDriver(&tb67H450);
    motor.AttachEncoder(&mt6816);
    motor.controller->Init();
    motor.driver->Init();
    motor.encoder->Init();


    /*------------- Init peripherals -------------*/
    button1.SetOnEventListener(OnButton1Event);
    button2.SetOnEventListener(OnButton2Event);


    /*------- Start Close-Loop Control Tick ------*/
    HAL_Delay(100);
    HAL_TIM_Base_Start_IT(&htim1);  // 100Hz
    HAL_TIM_Base_Start_IT(&htim4);  // 20kHz

    if (button1.IsPressed() && button2.IsPressed())
        encoderCalibrator.isTriggered = true;
//    printf("start motor %d\r\n", defaultNodeID);

    for (;;)
    {
//        if ( encoderCalibrator.FlashRun() == 0)
            encoderCalibrator.TickMainLoop();

        if (boardConfig.configStatus == CONFIG_COMMIT)
        {
            boardConfig.configStatus = CONFIG_OK;
            eeprom.put(0, boardConfig);
        } else if (boardConfig.configStatus == CONFIG_RESTORE)
        {
            eeprom.put(0, boardConfig);
            HAL_NVIC_SystemReset();
        }
    }
}


/* Event Callbacks -----------------------------------------------------------*/
//let's add a global count in here for quick test
uint32_t count;
extern "C" void Tim1Callback100Hz()
{
    __HAL_TIM_CLEAR_IT(&htim1, TIM_IT_UPDATE);

    button1.Tick(10);
    button2.Tick(10);
    statusLed.Tick(10, motor.controller->state);
    //1s period to collect a temperature data
    if (boardConfig.enableTempWatch)
    {
        count ++;
        if ( count >= 100)
        {
            boardConfig.motor_temperature = AdcGetChipTemperature();
            count = 0;
        }
        if (count > 50)
        {
            statusLed.Status(1, true);
        }
        else
        {
            statusLed.Status(1, false);
        }
    }
}


extern "C" void Tim4Callback20kHz()
{
    __HAL_TIM_CLEAR_IT(&htim4, TIM_IT_UPDATE);

    if (encoderCalibrator.isTriggered)
        encoderCalibrator.Tick20kHz();
    else
        motor.Tick20kHz();
}


void OnButton1Event(Button::Event _event)
{
    switch (_event)
    {
        case ButtonBase::UP:
            break;
        case ButtonBase::DOWN:
            break;
        case ButtonBase::LONG_PRESS:
            encoderCalibrator.isTriggered = true;
            encoderCalibrator.Tick20kHz();
            encoderCalibrator.TickMainLoop();
//            HAL_NVIC_SystemReset();
//            encoderCalibrator.TestFlash();
            break;
        case ButtonBase::CLICK:
            printf("KEY1\r\n");
            if (motor.controller->modeRunning != Motor::MODE_STOP)
            {
                boardConfig.defaultMode = motor.controller->modeRunning;
                motor.controller->requestMode = Motor::MODE_STOP;
            } else
            {
                motor.controller->requestMode = static_cast<Motor::Mode_t>(boardConfig.defaultMode);
            }
            break;
    }
}


void OnButton2Event(Button::Event _event)
{
    switch (_event)
    {
        case ButtonBase::UP:
            break;
        case ButtonBase::DOWN:
            break;
        case ButtonBase::LONG_PRESS:
            switch (motor.controller->modeRunning)
            {
                case Motor::MODE_COMMAND_CURRENT:
                case Motor::MODE_PWM_CURRENT:
                    motor.controller->SetCurrentSetPoint(0);
                    break;
                case Motor::MODE_COMMAND_VELOCITY:
                case Motor::MODE_PWM_VELOCITY:
                    motor.controller->SetVelocitySetPoint(0);
                    break;
                case Motor::MODE_COMMAND_POSITION:
                case Motor::MODE_PWM_POSITION:
                    motor.controller->SetPositionSetPoint(0);
                    break;
                case Motor::MODE_COMMAND_Trajectory:
                case Motor::MODE_STEP_DIR:
                case Motor::MODE_STOP:
                    break;
            }
            break;
        case ButtonBase::CLICK:
            printf("KEY2\r\n");
            motor.controller->ClearStallFlag();
            break;
    }
}

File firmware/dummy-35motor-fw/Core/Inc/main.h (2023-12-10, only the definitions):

#define ID0_Pin GPIO_PIN_8
#define ID0_GPIO_Port GPIOA
#define ID1_Pin GPIO_PIN_9
#define ID1_GPIO_Port GPIOA
#define ID2_Pin GPIO_PIN_10
#define ID2_GPIO_Port GPIOA
#define LED1_Pin GPIO_PIN_13
#define LED1_GPIO_Port GPIOC
#define LED2_Pin GPIO_PIN_14
#define LED2_GPIO_Port GPIOC
#define POWER_U_Pin GPIO_PIN_0
#define POWER_U_GPIO_Port GPIOA
#define DRV_TEMP_Pin GPIO_PIN_1
#define DRV_TEMP_GPIO_Port GPIOA
#define HW_ELEC_BM_Pin GPIO_PIN_2
#define HW_ELEC_BM_GPIO_Port GPIOA
#define HW_ELEC_BP_Pin GPIO_PIN_3
#define HW_ELEC_BP_GPIO_Port GPIOA
#define HW_ELEC_AM_Pin GPIO_PIN_4
#define HW_ELEC_AM_GPIO_Port GPIOA
#define HW_ELEC_AP_Pin GPIO_PIN_5
#define HW_ELEC_AP_GPIO_Port GPIOA
#define SIGNAL_COUNT_DIR_Pin GPIO_PIN_7
#define SIGNAL_COUNT_DIR_GPIO_Port GPIOA
#define SIGNAL_COUNT_DIR_EXTI_IRQn EXTI9_5_IRQn
#define SIGNAL_COUNT_EN_Pin GPIO_PIN_0
#define SIGNAL_COUNT_EN_GPIO_Port GPIOB
#define SIGNAL_ALERT_Pin GPIO_PIN_1
#define SIGNAL_ALERT_GPIO_Port GPIOB
#define BUTTON2_Pin GPIO_PIN_2
#define BUTTON2_GPIO_Port GPIOB
#define HW_ELEC_BPWM_Pin GPIO_PIN_10
#define HW_ELEC_BPWM_GPIO_Port GPIOB
#define HW_ELEC_APWM_Pin GPIO_PIN_11
#define HW_ELEC_APWM_GPIO_Port GPIOB
#define BUTTON1_Pin GPIO_PIN_12
#define BUTTON1_GPIO_Port GPIOB
#define SPI1_CS_Pin GPIO_PIN_15
#define SPI1_CS_GPIO_Port GPIOA

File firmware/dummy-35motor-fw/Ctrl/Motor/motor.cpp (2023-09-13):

#include "configurations.h"
#include "motor.h"

#include <cmath>


void Motor::Tick20kHz()
{
    // 1.Encoder data Update
    encoder->UpdateAngle();

    // 2.Motor Control Update
    CloseLoopControlTick();
}


void Motor::AttachEncoder(EncoderBase* _encoder)
{
    encoder = _encoder;
}


void Motor::AttachDriver(DriverBase* _driver)
{
    driver = _driver;
}


void Motor::CloseLoopControlTick()
{
    /************************************ First Called ************************************/
    static bool isFirstCalled = true;
    if (isFirstCalled)
    {
        int32_t angle;
        if (config.motionParams.encoderHomeOffset < MOTOR_ONE_CIRCLE_SUBDIVIDE_STEPS / 2)
        {
            angle =
                encoder->angleData.rectifiedAngle >
                config.motionParams.encoderHomeOffset + MOTOR_ONE_CIRCLE_SUBDIVIDE_STEPS / 2 ?
                encoder->angleData.rectifiedAngle - MOTOR_ONE_CIRCLE_SUBDIVIDE_STEPS :
                encoder->angleData.rectifiedAngle;
        } else
        {
            angle =
                encoder->angleData.rectifiedAngle <
                config.motionParams.encoderHomeOffset - MOTOR_ONE_CIRCLE_SUBDIVIDE_STEPS / 2 ?
                encoder->angleData.rectifiedAngle + MOTOR_ONE_CIRCLE_SUBDIVIDE_STEPS :
                encoder->angleData.rectifiedAngle;
        }

        controller->realLapPosition = angle;
        controller->realLapPositionLast = angle;
        controller->realPosition = angle;
        controller->realPositionLast = angle;

        isFirstCalled = false;
        return;
    }

    /********************************* Update Data *********************************/
    int32_t deltaLapPosition;

    // Read Encoder data
    controller->realLapPositionLast = controller->realLapPosition;
    controller->realLapPosition = encoder->angleData.rectifiedAngle;

    // Lap-Position calculate
    deltaLapPosition = controller->realLapPosition - controller->realLapPositionLast;
    if (deltaLapPosition > MOTOR_ONE_CIRCLE_SUBDIVIDE_STEPS >> 1)
        deltaLapPosition -= MOTOR_ONE_CIRCLE_SUBDIVIDE_STEPS;
    else if (deltaLapPosition < -MOTOR_ONE_CIRCLE_SUBDIVIDE_STEPS >> 1)
        deltaLapPosition += MOTOR_ONE_CIRCLE_SUBDIVIDE_STEPS;

    // Naive-Position calculate
    controller->realPositionLast = controller->realPosition;
    controller->realPosition += deltaLapPosition;

    /********************************* Estimate Data *********************************/
    // Estimate Velocity
    controller->estVelocityIntegral += (
        (controller->realPosition - controller->realPositionLast) * motionPlanner.CONTROL_FREQUENCY
        + ((controller->estVelocity << 5) - controller->estVelocity)
    );
    controller->estVelocity = controller->estVelocityIntegral >> 5;
    controller->estVelocityIntegral -= (controller->estVelocity << 5);

    // Estimate Position
    controller->estLeadPosition = Controller::CompensateAdvancedAngle(controller->estVelocity);
    controller->estPosition = controller->realPosition + controller->estLeadPosition;

    // Estimate Error
    controller->estError = controller->softPosition - controller->estPosition;

    /************************************ Ctrl Loop ************************************/
    if (controller->isStalled ||
        controller->softDisable ||
        !encoder->IsCalibrated())
    {
        controller->ClearIntegral();    // clear integrals
        controller->focPosition = 0;    // clear outputs
        controller->focCurrent = 0;
        driver->Sleep();
    } else if (controller->softBrake)
    {
        controller->ClearIntegral();
        controller->focPosition = 0;
        controller->focCurrent = 0;
        driver->Brake();
    } else
    {
        switch (controller->modeRunning)
        {
            case MODE_STEP_DIR:
                controller->CalcDceToOutput(controller->softPosition, controller->softVelocity);
                break;
            case MODE_STOP:
                driver->Sleep();
                break;
            case MODE_COMMAND_Trajectory:
                controller->CalcDceToOutput(controller->softPosition, controller->softVelocity);
                break;
            case MODE_COMMAND_CURRENT:
                controller->CalcCurrentToOutput(controller->softCurrent);
                break;
            case MODE_COMMAND_VELOCITY:
                controller->CalcPidToOutput(controller->softVelocity);
                break;
            case MODE_COMMAND_POSITION:
                controller->CalcDceToOutput(controller->softPosition, controller->softVelocity);
                break;
            case MODE_PWM_CURRENT:
                controller->CalcCurrentToOutput(controller->softCurrent);
                break;
            case MODE_PWM_VELOCITY:
                controller->CalcPidToOutput(controller->softVelocity);
                break;
            case MODE_PWM_POSITION:
                controller->CalcDceToOutput(controller->softPosition, controller->softVelocity);
                break;
            default:
                break;
        }
    }

    /******************************* Mode Change Handle *******************************/
    if (controller->modeRunning != controller->requestMode)
    {
        controller->modeRunning = controller->requestMode;
        controller->softNewCurve = true;
    }

    /******************************* Update Hard-Goal *******************************/
    if (controller->goalVelocity > config.motionParams.ratedVelocity)
        controller->goalVelocity = config.motionParams.ratedVelocity;
    else if (controller->goalVelocity < -config.motionParams.ratedVelocity)
        controller->goalVelocity = -config.motionParams.ratedVelocity;
    if (controller->goalCurrent > config.motionParams.ratedCurrent)
        controller->goalCurrent = config.motionParams.ratedCurrent;
    else if (controller->goalCurrent < -config.motionParams.ratedCurrent)
        controller->goalCurrent = -config.motionParams.ratedCurrent;

    /******************************** Motion Plan *********************************/
    if ((controller->softDisable && !controller->goalDisable) ||
        (controller->softBrake && !controller->goalBrake))
    {
        controller->softNewCurve = true;
    }

    if (controller->softNewCurve)
    {
        controller->softNewCurve = false;
        controller->ClearIntegral();
        controller->ClearStallFlag();
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

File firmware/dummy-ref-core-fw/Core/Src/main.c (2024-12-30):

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
/* Includes ------------------------------------------------------------------*/
#include "main.h"
#include "cmsis_os.h"
#include "adc.h"
#include "can.h"
#include "dma.h"
#include "i2c.h"
#include "spi.h"
#include "tim.h"
#include "usart.h"
#include "usb_device.h"
#include "gpio.h"


/* USER CODE BEGIN PV */
uint64_t serialNumber;
uint64_t myserial = 8;
char serialNumberStr[13];
__attribute__((section(".ccmram"))) uint8_t ucHeap[configTOTAL_HEAP_SIZE];
/* USER CODE END PV */

void SystemClock_Config(void);
void MX_FREERTOS_Init(void);
/**
  * @brief  The application entry point.
  * @retval int
  */
int main(void)
{
  /* USER CODE BEGIN 1 */

    // This procedure of building a USB serial number should be identical
    // to the way the STM's built-in USB bootloader does it. This means
    // that the device will have the same serial number in normal and DFU mode.
    uint32_t uuid0 = *(uint32_t *) (UID_BASE + 0);
    uint32_t uuid1 = *(uint32_t *) (UID_BASE + 4);
    uint32_t uuid2 = *(uint32_t *) (UID_BASE + 8);
    uint32_t uuid_mixed_part = uuid0 + uuid2;
    serialNumber = ((uint64_t) uuid_mixed_part << 16) | (uint64_t) (uuid1 >> 16);

    uint64_t val = serialNumber;
    for (size_t i = 0; i < 12; ++i)
    {
        serialNumberStr[i] = "0123456789ABCDEF"[(val >> (48 - 4)) & 0xf];
        val <<= 4;
    }
    serialNumberStr[12] = 0;

  /* USER CODE END 1 */

  /* MCU Configuration--------------------------------------------------------*/

  /* Reset of all peripherals, Initializes the Flash interface and the Systick. */
  HAL_Init();

  /* USER CODE BEGIN Init */
  HAL_RCC_DeInit();

  /* USER CODE END Init */

  /* Configure the system clock */
  SystemClock_Config();

  /* Initialize all configured peripherals */
  MX_GPIO_Init();
  MX_DMA_Init();
  MX_I2C1_Init();
  MX_I2C2_Init();
  MX_CAN1_Init();
  MX_CAN2_Init();
  MX_USART1_UART_Init();
  MX_I2C3_Init();
  MX_SPI1_Init();
  MX_SPI3_Init();
  MX_UART4_Init();
  MX_ADC1_Init();
  MX_UART5_Init();
  MX_TIM2_Init();
  MX_TIM3_Init();
  /* Init scheduler */
  osKernelInitialize();  /* Call init function for freertos objects (in freertos.c) */
  MX_FREERTOS_Init();
  /* Start scheduler */
  osKernelStart();

  /* We should never get here as control is now taken by the scheduler */
  /* Infinite loop */
  /* USER CODE BEGIN WHILE */

    while (1)
    {
    /* USER CODE END WHILE */

    /* USER CODE BEGIN 3 */
    }
  /* USER CODE END 3 */
}

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
/* USER CODE BEGIN 4 */
void OnTimerCallback(TIM_TypeDef *timInstance);
/* USER CODE END 4 */

 /**
  * @brief  Period elapsed callback in non blocking mode
  * @note   This function is called  when TIM6 interrupt took place, inside
  * HAL_TIM_IRQHandler(). It makes a direct call to HAL_IncTick() to increment
  * a global variable "uwTick" used as application time base.
  * @param  htim : TIM handle
  * @retval None
  */
void HAL_TIM_PeriodElapsedCallback(TIM_HandleTypeDef *htim)
{
  if (htim->Instance == TIM6) {
    HAL_IncTick();
  }
  /* USER CODE BEGIN Callback 1 */
  else
  {
      OnTimerCallback(htim->Instance);
  }
  /* USER CODE END Callback 1 */
}

/**
  * @brief  This function is executed in case of error occurrence.
  * @retval None
  */
void Error_Handler(void)
{
  /* USER CODE BEGIN Error_Handler_Debug */
    /* User can add his own implementation to report the HAL error return state */
    __disable_irq();
    while (1)
    {
    }
  /* USER CODE END Error_Handler_Debug */
}

#ifdef  USE_FULL_ASSERT
/**
  * @brief  Reports the name of the source file and the source line number
  *         where the assert_param error has occurred.
  * @param  file: pointer to the source file name
  * @param  line: assert_param error line source number
  * @retval None
  */
void assert_failed(uint8_t *file, uint32_t line)
{
  /* USER CODE BEGIN 6 */
  /* User can add his own implementation to report the file name and line number,
     ex: printf("Wrong parameters value: file %s on line %d\r\n", file, line) */
  /* USER CODE END 6 */
}
#endif /* USE_FULL_ASSERT */

/************************ (C) COPYRIGHT STMicroelectronics *****END OF FILE****/

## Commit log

2023-09-13 fist commit
    [configurations.h, stlink.cfg]
2023-09-14 add schemiatc, pcb and 3d bracket model
    [42motor-bracket-bot.stl, Drive.SchDoc, Interface.SchDoc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]
2023-09-14 add 42 motor picture
2023-09-15 add 42 motor description of improved
2023-09-16 fix sometimes turning the power switch on and off will cause the firmware to freeze.
    [main.cpp]
2023-09-17 Added support for dummy studios and fixed some minor bugs.
    [ctrl_step.cpp, dummy_robot.cpp, main.c]
2023-09-21 add BOM list for quick reference, to get the detailed BOM you have to open the schematics
    [Motor-42.xlsx]
2023-09-30 add BLDC motor design
    [Motor-BLDC.SchDoc]
2023-09-30 relayout motor-bldc folder
    [Motor-BLDC.SchDoc]
2023-09-30 add bldc motor bracket 3d model
    [bldc-bracket.stl]
2023-09-30 add motor-bldc.
2023-09-30 update motor-bldc/README.md. add readme file
2023-09-30 add bldc image
2023-11-03 add dummy esp32 iot firmware
2023-11-14 add latest 3d models for community, beware that is still under development, it will change without notice
    [base.stl, joint1.stl, joint23.stl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]
2023-11-16 add dummy iot firmware source code
    [partitions.csv]
2023-11-23 add ref contorller board, m42, m35 boards designs
    [42motor-bracket-bot.stl, Drive.SchDoc, Interface.SchDoc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]
2023-11-23 add ref contorller board, m42, m35 boards hardware designs
    [Drive.SchDoc, Interface.SchDoc, MCU.SchDoc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]
2023-11-23 relayout 3d models folder
    [contorller-oled-bracket.stl, motor-35-bot.stl, motor-35-top.stl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]
2023-11-23 remove bldc folder for this branch
    [Motor-BLDC.SchDoc, bldc-bracket.stl]
2023-11-23 add latest base and ref controller enclosure stl
    [base.stl, controller_enclosure.stl]
2023-12-10 add latest motor 42/35 code to support Muzi Xiaowen's driver board
    [configurations.h]
2023-12-10 add belts caculation tools
2023-12-19 add tweaking motor pid commands
2023-12-19 add latest 3d printed models
    [base.stl, controller_enclosure.stl, j1.stl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]
2023-12-25 add rgb led ring support
2023-12-27 add full code of WS2812 rgb driver
2024-05-09 upload new board's images
2024-07-29 add dummy ros2 workspace files
    [base_link.stl, dummy-ros2.ros2_control.xacro, dummy-ros2.urdf.xacro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]
2025-02-17 end CalibrateHomeOffset by wanghao 2025.2.17
2025-02-18 end expect //!这个 by wanghao 2025.2.18

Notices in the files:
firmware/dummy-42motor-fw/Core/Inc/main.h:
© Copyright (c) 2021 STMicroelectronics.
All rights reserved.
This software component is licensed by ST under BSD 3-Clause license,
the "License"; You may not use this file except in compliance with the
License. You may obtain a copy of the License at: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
